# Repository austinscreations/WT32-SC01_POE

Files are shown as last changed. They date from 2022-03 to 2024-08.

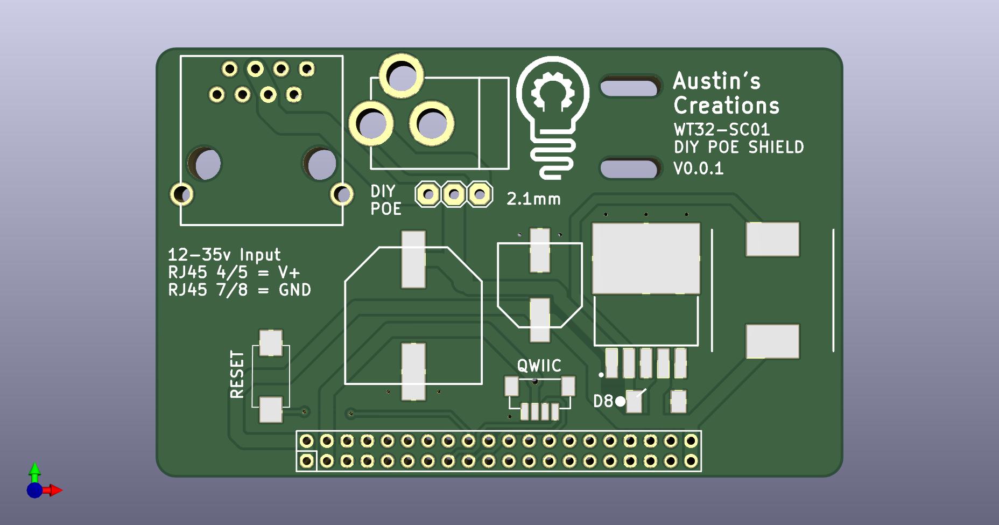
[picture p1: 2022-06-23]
WiFi POE shield/PCB/pictures/WT32SC01 wifi poe top.jpg

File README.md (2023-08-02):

# WT32-SC01_POE

2023-06-28:

New sheild has been designed that is more universal. the deisgn is much smaller. uses a single 1.25mm jst conenctor to connect to the wt32-sc01 PLUS display.
adapter has been built for the WT32-S3-86s (replaces the 86v) 4" display. adapter in the works to support the orginal display as well

2022-06-23: renamed the repo as this project has evolved

There are now two shields designed for the wt32-sc01 display.
- one offers Ethernet + 802.1af POE
- second offers passive 12-24v POE + a 2.1mm jack

the thought with a passive board is that it's smaller allowing for more compact case designs to be built. and if you prefer to use 802.1af POE with the 2.1mm jack you can very eaily use a standard POE injector that normally cost about $6 from aliexpress to gain such functionality. with teh apssive baord however you are limited to using wifi.

both shields also equipped with qwiic connector for easy i2c support

designed for the use case of using the panel for homeautomation, code and gui in progress.

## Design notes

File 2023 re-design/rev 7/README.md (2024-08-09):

latest version of the WT32 Ethernet POE
works directly on the WT32-SC01 Plus, and adapters will be availble for the orginal Wt32 screen and the square 86s/86v screen

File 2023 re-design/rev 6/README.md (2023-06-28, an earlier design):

# things to note

With the 86v panel you'd need both the POE module but also the adapter. along with doing modifications to the panel PCB to accept ethernet.
video of doing this modification here: <https://www.youtube.com/watch?v=REbtDBVKIto>

even with doing JLCPCBs PCBA you will need to add the ethernet jack - from mouser ARJM11D7-114-AB-EW2
I've been sourcing the POE from aliexpress - it has 2 pins on one end, 4 on the other. 12v output SDAPO DP1435
Then you need an 8 pin 1.25mm dual head JST connector. pinout should be the same pin 1 to pin 1 etc. i've been buying these from aliexpress in 100mmm length

Becuase part numbers and links change somewhat often i won't post any here but feel free to reach out on discord if you need help.

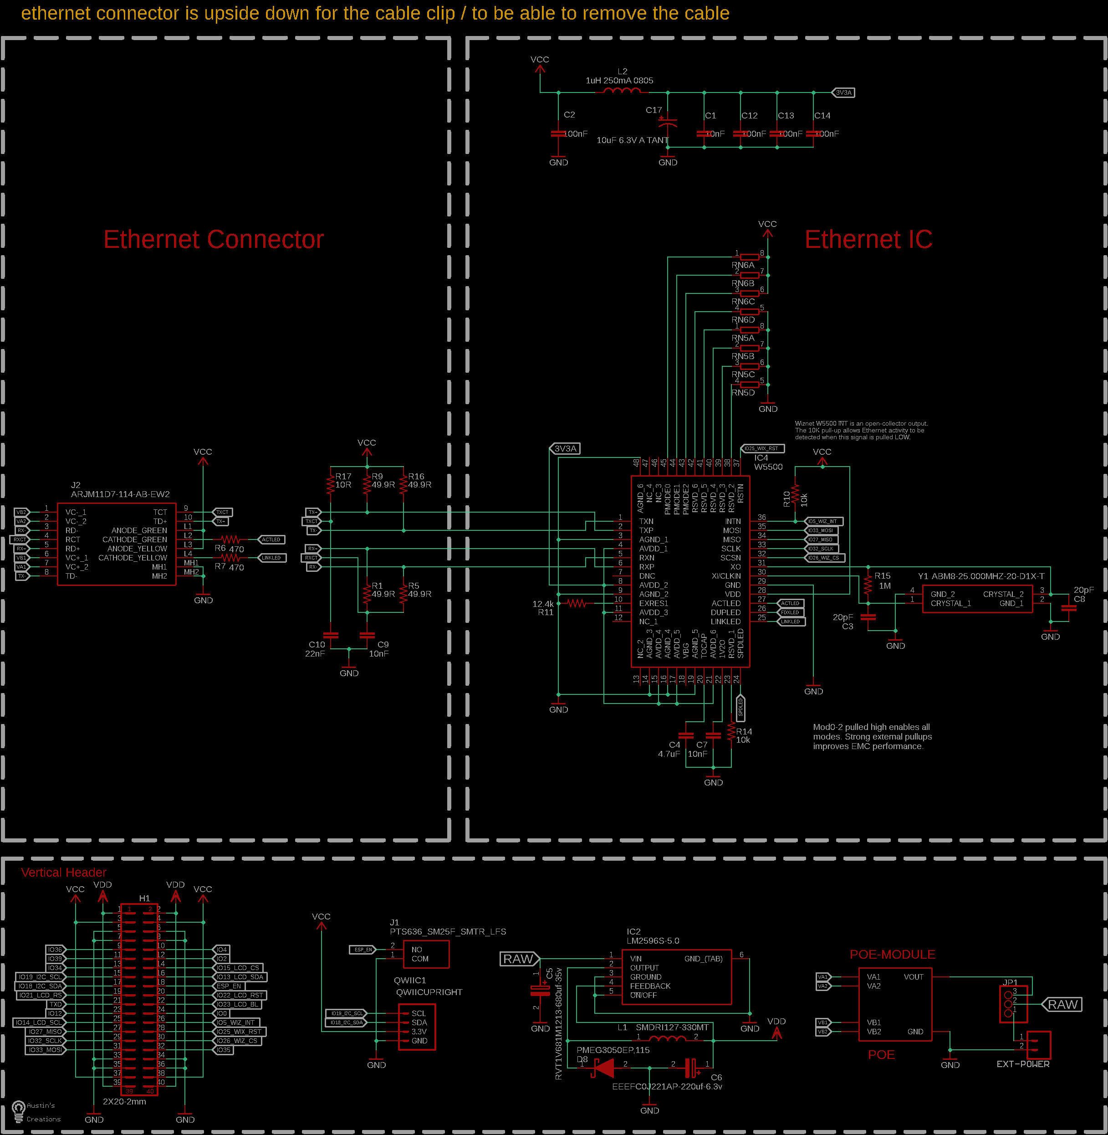
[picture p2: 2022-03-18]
Ethernet POE shield/PCB/pictures/schematic.png

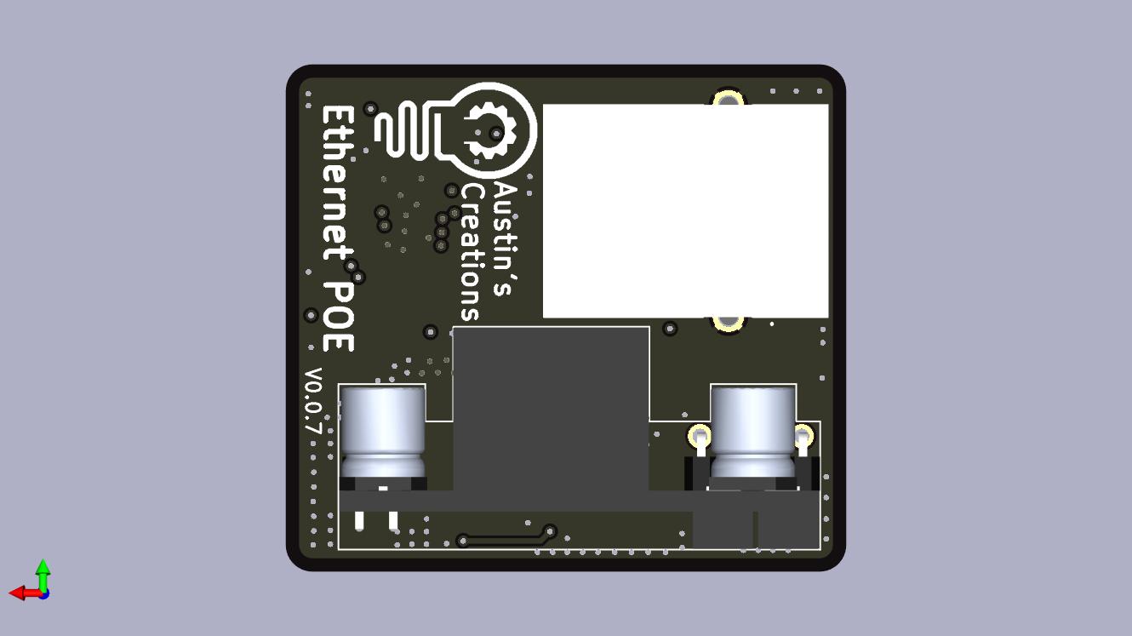
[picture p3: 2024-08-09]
2023 re-design/rev 7/WT32 ethernet POE 007 bottom.jpg

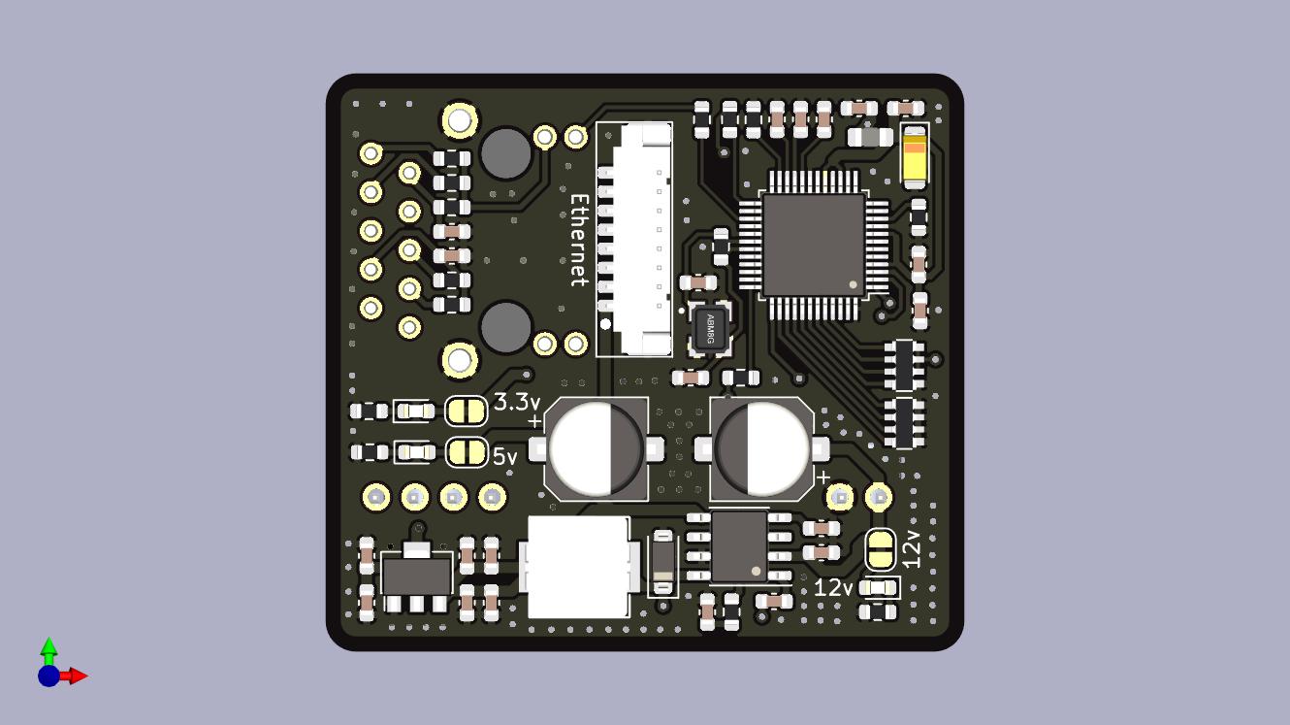
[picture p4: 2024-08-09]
2023 re-design/rev 7/WT32 ethernet POE 007 top.jpg

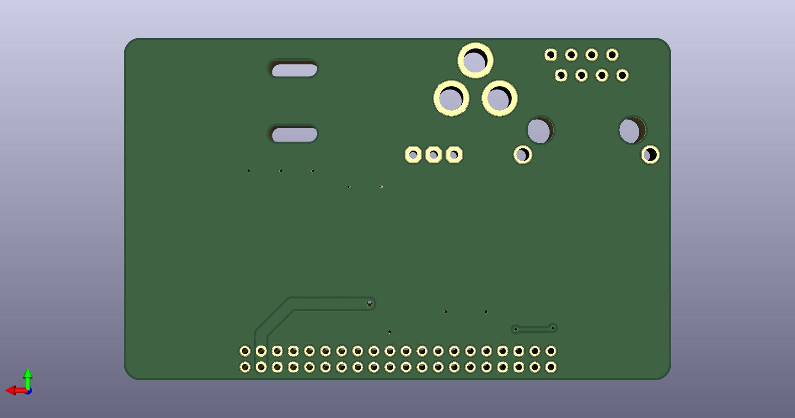
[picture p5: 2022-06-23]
WiFi POE shield/PCB/pictures/WT32SC01 wifi poe bottom.jpg

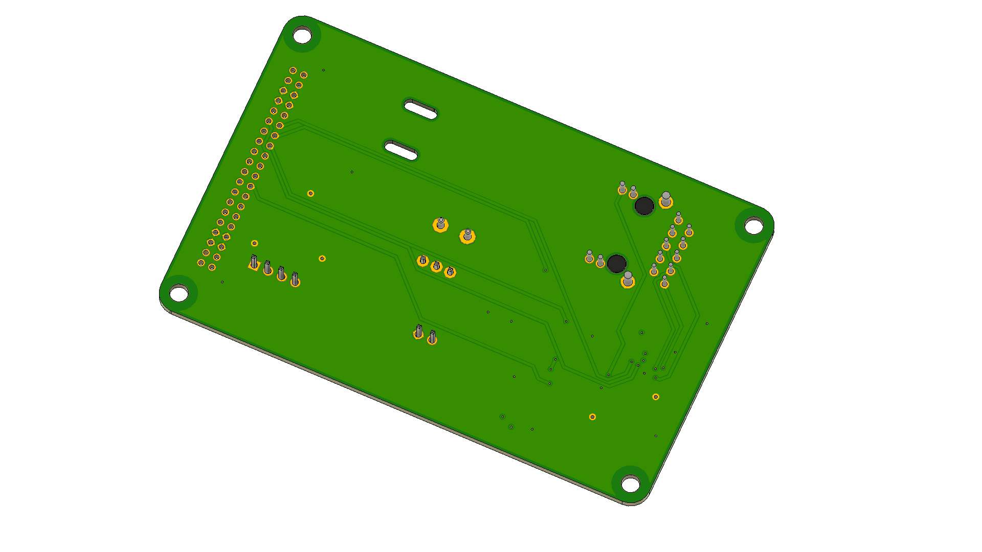
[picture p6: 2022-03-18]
Ethernet POE shield/PCB/pictures/WT32SC01-POE bottom.png

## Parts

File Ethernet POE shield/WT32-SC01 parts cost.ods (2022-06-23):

Part | Part Number | needed qty | cost | Purchase qty | per item | total | brd qty | current stock | total needed
680uf-35v | C98216 | 1 | 4.37 | 10 | 0.437 | 0.437 | 0 |  | 0
220uf-6.3v | C401613 | 1 | 4.39 | 30 | 0.1463333333 | 0.1463333333 | 0 |  | 0
0603 20pf | C105621 | 2 | 2.05 | 500 | 0.0041 | 0.0082 | 0 |  | 0
0603 4.7uF | C152930 | 1 | 3.92 | 200 | 0.0196 | 0.0196 | 0 |  | 0
0603 22nf | C302044 | 1 | 3.55 | 500 | 0.0071 | 0.0071 | 0 |  | 0
0603 10nf | C141077 | 2 | 4.6 | 500 | 0.0092 | 0.0184 | 0 |  | 0
0603 100nf | C83060 | 8 | 1.6 | 500 | 0.0032 | 0.0256 | 0 |  | 0
buttons | C410373 | 2 | 6.12 | 100 | 0.0612 | 0.1224 | 0 |  | 0
Ethernet connector |  | 1 | 6 | 1 | 6 | 6 | 0 |  | 0
25mhz crystal | C258949 | 1 | 6.09 | 50 | 0.1218 | 0.1218 | 0 |  | 0
POE module |  | 1 | 31.54 | 5 | 6.308 | 6.308 | 0 |  | 0
4pin jst sh | C145956 | 2 | 6.4 | 120 | 0.0533333333 | 0.1066666667 | 0 |  | 0
PMEG4050EP Diode | C96235 | 2 | 2.7 | 10 | 0.27 | 0.54 | 0 |  | 0
2pin terminal block | C192779 | 1 | 1.98 | 10 | 0.198 | 0.198 | 0 |  | 0
LM2596S-5.0 | C347421 | 1 | 7.09 | 10 | 0.709 | 0.709 | 0 |  | 0
w5500 Ethernet IC | C32843 | 1 | 7.94 | 1 | 7.94 | 7.94 | 0 |  | 0
330mt inductor | C9400 | 1 | 5.43 | 30 | 0.181 | 0.181 | 0 |  | 0
1x3 pin header | C213447 | 1 | 2.56 | 1500 | 0.0017066667 | 0.0017066667 | 0 |  | 0
0603 resistor 10ohm | C103222 | 1 | 1.7 | 1000 | 0.0017 | 0.0017 | 0 |  | 0
0603 resistor 49.9ohm | C103679 | 4 | 1.7 | 1000 | 0.0017 | 0.0068 | 0 |  | 0
0603 resistor 470 ohm | C25241 | 3 | 1.1 | 1000 | 0.0011 | 0.0033 | 0 |  | 0
0603 resistor 10k | C103199 | 2 | 1.7 | 1000 | 0.0017 | 0.0034 | 0 |  | 0
0603 resistor 12.4k | C269455 | 1 | 3 | 1000 | 0.003 | 0.003 | 0 |  | 0
0603 resistor 1M | C328343 | 1 | 2.9 | 1000 | 0.0029 | 0.0029 | 0 |  | 0
resistor network 10k | C29718 | 4 | 3.2 | 500 | 0.0064 | 0.0256 | 0 |  | 0
1uH 250mA 0805 | C98325 | 1 | 1.29 | 20 | 0.0645 | 0.0645 | 0 |  | 0
10uF tant capacitor | C127946 | 1 | 3.71 | 50 | 0.0742 | 0.0742 | 0 |  | 0
2x20 pin header 2mm | C376094 | 1 | 3.04 | 10 | 0.304 | 0.304 | 0
PCB's |  | 1 | 90 | 10 | 9 | 9 | 0
 | total creates % | % creates total
Total | 80 | 68.09
Markup | 52.73% | 30.00%
board cost | 52.38
purchase cost | 0.00
Shop 1 (pcb's) | 9.00
Shop 2 (aliexpress)
Shop 3 (lcsc) | 43.38
Automated assembly
Part | Part Number | needed qty | cost | Purchase qty | per item | total | brd qty | current stock | total needed
JLCPCB 10pcs |  | 1 | 260 | 10 | 26 | 26 | 0
POE module |  | 1 | 31.54 | 5 | 6.308 | 6.308
Ethernet connector |  | 1 | 6 | 1 | 6 | 6
4pin jst sh | C145956 | 2 | 6.4 | 120 | 0.0533333333 | 0.1066666667
1x3 pin header | C213447 | 1 | 2.56 | 1500 | 0.0017066667 | 0.0017066667
2x20 pin header 2mm | C376094 | 1 | 3.04 | 10 | 0.304 | 0.304
JLCPCB 50pcs |  | 1 | 660 | 50 | 13.2 | 13.2
Total | 60 | 50
Markup | 23.15% | 39.20%
 |  |  | 11.2796266667 | 14.08
board cost | 48.72
board cost | 35.92
Shop 1 (pcb's) | 26.00 | 13.2
Shop 2 ()
Shop 3 (parts) | 22.72 | 22.72

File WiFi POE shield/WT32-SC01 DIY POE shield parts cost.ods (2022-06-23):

Part | Part Number | needed qty | cost | Purchase qty | per item | total | brd qty | current stock | total needed
680uf-35v | C98216 | 1 | 4.37 | 10 | 0.437 | 0.437 | 0 |  | 0
220uf-6.3v | C401613 | 1 | 4.39 | 30 | 0.1463333333 | 0.1463333333 | 0 |  | 0 | C2895278
LM2596S-5.0 | C347421 | 1 | 7.09 | 10 | 0.709 | 0.709 | 0 |  | 0
330mt inductor | C9400 | 1 | 5.43 | 30 | 0.181 | 0.181 | 0 |  | 0
PMEG4050EP Diode | C96235 | 1 | 2.7 | 10 | 0.27 | 0.27 | 0 |  | 0
2.1mm power jack | C319099 | 1 | 3.95 | 50 | 0.079 | 0.079 | 0 |  | 0
1x3 pin header | C213447 | 1 | 2.56 | 1500 | 0.0017066667 | 0.0017066667 | 0 |  | 0
buttons | C410373 | 1 | 6.12 | 100 | 0.0612 | 0.0612 | 0 |  | 0
Ethernet connector | C386763 | 1 | 5.69 | 10 | 0.569 | 0.569 | 0 |  | 0
4pin jst sh vertical | C145961 | 1 | 8.29 | 120 | 0.0690833333 | 0.0690833333 | 0 |  | 0
2x20 pin header 2mm | C376094 | 1 | 3.04 | 10 | 0.304 | 0.304 | 0 |  | 0
PCB's |  | 1 | 75 | 10 | 7.5 | 7.5 | 0 |  | 0
Total | 30
Markup | -1.08%
board cost | 30.33
purchase cost | 0.00
Shop 1 (pcb's) | 7.50
Shop 2 (aliexpress)
Shop 3 (lcsc) | 22.83
SMD assembly:
PCB's |  | 1 | 200 | 20 | 10 | 10 | 0 |  | 0
2.1mm power jack | C319099 | 1 | 3.95 | 50 | 0.079 | 0.079 | 0 |  | 0
2x20 pin header 2mm | C376094 | 1 | 3.04 | 10 | 0.304 | 0.304 | 0 |  | 0
1x3 pin header | C213447 | 1 | 2.56 | 1500 | 0.0017066667 | 0.0017066667 | 0 |  | 0
Total | 30
Markup | 188.89%
board cost | 10.38
purchase cost | 0.00
Shop 1 (pcb's) | 10.00
Shop 2 (aliexpress)
Shop 3 (lcsc) | 0.38

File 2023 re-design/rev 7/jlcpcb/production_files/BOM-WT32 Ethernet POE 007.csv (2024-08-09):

Comment | Designator | Footprint | LCSC
LM1117-3.3 | U3 | SOT-89-3 | C126019
10uF 6.3V A TANT | C7 | CP_EIA-3216-18_Kemet-A | C127946
100nF | C12,C13,C14,C16,C4 | C_0603_1608Metric | C14663
1uF | C22,C24 | C_0603_1608Metric | C15849
2.2nF | C6 | C_0603_1608Metric | C1604
20pF | C1,C2 | C_0603_1608Metric | C1648
4.7uF | C11 | C_0603_1608Metric | C19666
22nF | C17 | C_0603_1608Metric | C21122
Ethernet | J1 | 8 pin jst 1.25 vertical | C225110
10R | R12 | R_0603_1608Metric | C22859
1M | R1 | R_0603_1608Metric | C22935
470R | R10,R11 | R_0603_1608Metric | C23179
49.9R | R6,R7,R8,R9 | R_0603_1608Metric | C23185
10k | R13,R14,R15,R2,R3 | R_0603_1608Metric | C25804
47k | R4 | R_0603_1608Metric | C25819
25MHz_SMD_Crystal_Resonator | Y1 | 25MHz_SMD_Crystal_Resonator | C258949
10k | RN1,RN2 | R_Array_Convex_4x0603 | C29718
82uH 2A | L2 | IND-SMD_L7.1-W6.6 | C2983095
12.4k | R5 | R_0603_1608Metric | C310267
W5500 | U1 | LQFP-48_7x7mm_P0.5mm | C32843
TPS5405DR | U2 | SOIC-8_3.9x4.9mm_P1.27mm | C488409
150uF 25v | C18,C3 | CP_Elec_6.3x7.7 | C494825
10nF | C10,C15,C8,C9 | C_0603_1608Metric | C57112
red | D2,D3,D4 | LED_0603_1608Metric | C72038
DSK24 | D1 | D_SOD-123 | C908229
10uF 25v | C19,C20,C21,C23,C5 | C_0603_1608Metric | C96446
1uH 250mA 0805 | L1 | L_0805_2012Metric | C98325

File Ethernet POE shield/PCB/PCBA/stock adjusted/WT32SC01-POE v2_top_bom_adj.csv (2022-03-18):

Comment | Designator | Footprint | LCSC Part #
1M | R15 | R0603 | C328343
1uH 250mA 0805 | L2 | L2012C | C98325
4.7uF | C4 | C0603 | C152930
10R | R17 | R0603 | C103222
10k | R10 R14 | R0603 | C103199
10nF | C1 C7 C9 | C0603 | C57112
10uF 6.3V A TANT | C17 | A/3216-18W | C127946
12.4k | R11 | R0603 | C269455
20pF | C3 C8 | C0603 | C105621
22nF | C10 | C0603 | C302044
49.9R | R1 R5 R9 R16 | R0603 | C103679
100nF | C2 C12 C13 C14 | C0603 | C83060
470R | R6 R7 | R0603 | C25241
ABM8-25.000MHZ-20-D1X-T | Y1 | ABM825000MHZ10B1UT | C258949
EEEFC0J221AP-220uf-6.3v | C6 | CAPAE830X650N | C401614
LM2596S-5.0 | IC2 | TO170P1435X465-6N | C347421
PMEG4050EP 115 | D8 | PMEG4050EP115 | C96234
PTS636_SM25F_SMTR_LFS | J1 | PTS636SM25FSMTRLFS | C410373
QWIICUPRIGHT | QWIIC1 | BM04B-SRSS-TB | C145961
RVT1V681M1213-680uf-35v | C5 | CAPAE1350X1400N | C249685
SMDRI127-330MT | L1 | INDPM120120X800N | C9400
W5500 | IC4 | QFP50P900X900X160-48N | C32843
10k | RN5 RN6 | R1206 | C29718

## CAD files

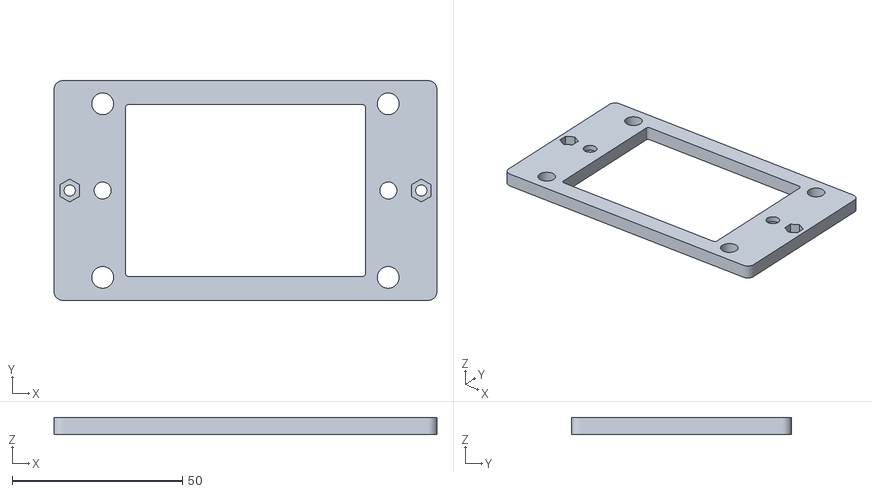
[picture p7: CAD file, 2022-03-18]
case designs/ethernet/AUS mount.stl
112.6 x 64.6 x 5.00

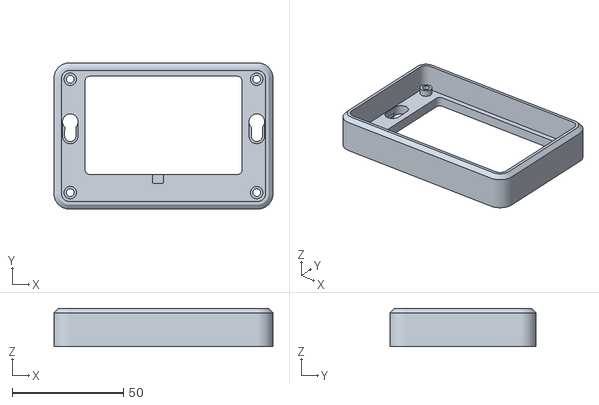
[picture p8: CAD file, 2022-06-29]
case designs/wifi/no usb access/WT32-SC01 wifi case AUS 3mm standoff no usb.stl
98.6 x 65.8 x 17.2

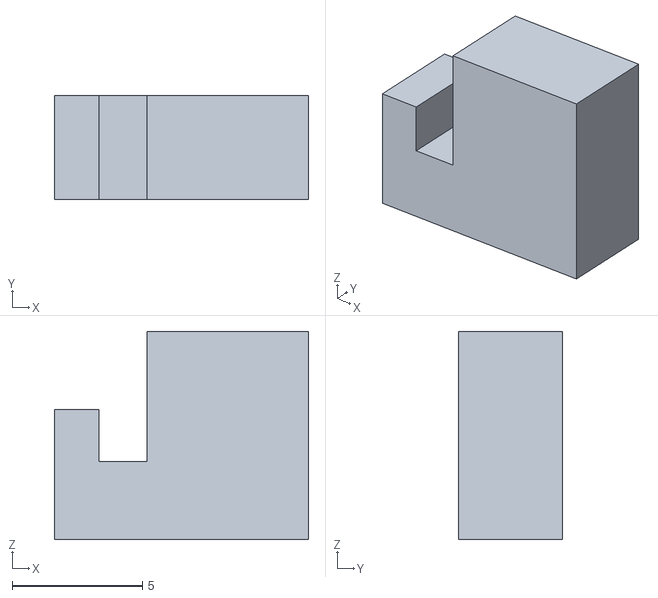
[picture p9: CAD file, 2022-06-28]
case designs/wifi/wifi pcb clip.stl
9.75 x 4.00 x 8.00

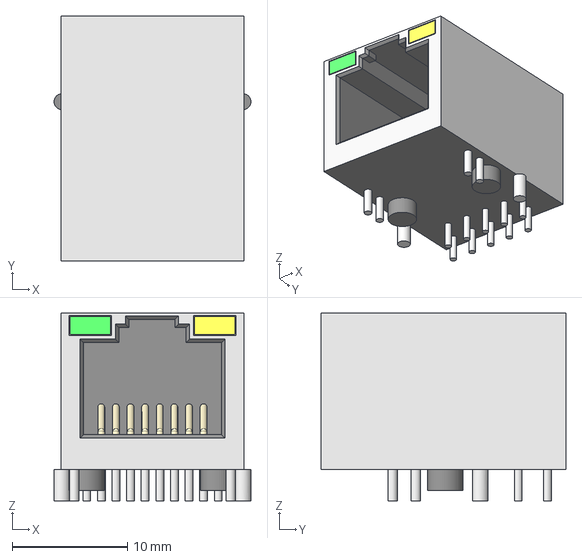
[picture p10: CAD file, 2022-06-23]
Ethernet POE shield/PCB/CAD/ARJM11D7114ABEW2.step
17.1 x 21.3 x 16.3 mm

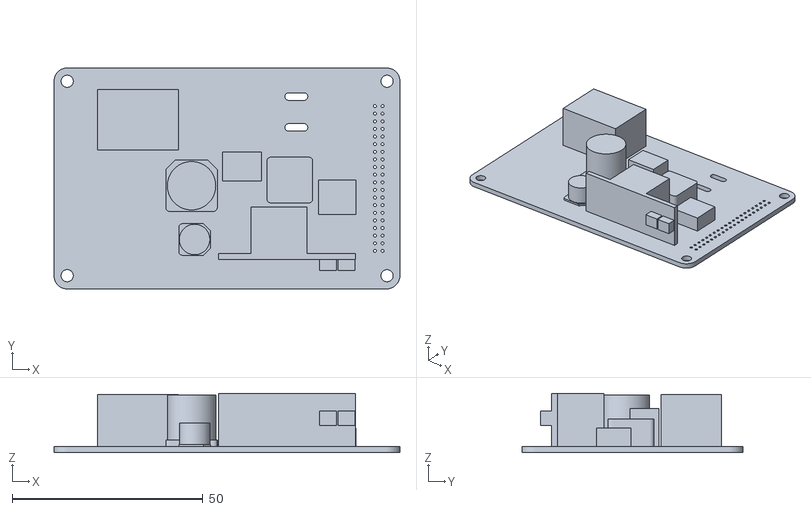
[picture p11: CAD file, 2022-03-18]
case designs/ethernet/sheild test v0.0.1.stl
90.8 x 58.0 x 15.6

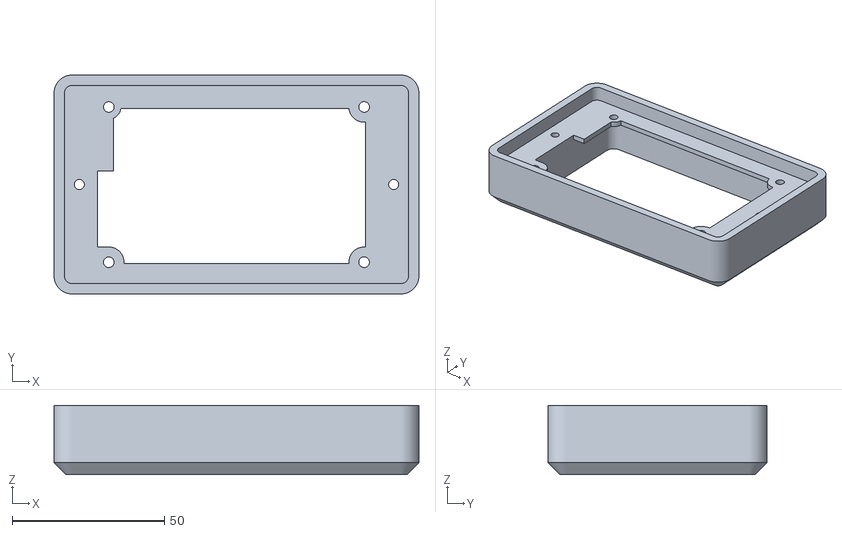
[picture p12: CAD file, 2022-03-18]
case designs/ethernet/screen case extra height.stl
120.0 x 72.0 x 22.8

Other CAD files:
case designs/wifi/no usb access/WT32-SC01 wifi case NA 3mm standoff no usb.stl
case designs/wifi/WT32-SC01 wifi case AUS 3mm standoff.stl
case designs/wifi/no usb access/WT32-SC01 wifi case AUS 6mm standoff no usb.stl
case designs/wifi/WT32-SC01 wifi case NA 3mm standoff.stl
case designs/ethernet/NA mount.stl
case designs/wifi/no usb access/WT32-SC01 wifi case NA 6mm standoff no usb.stl
case designs/wifi/WT32-SC01 wifi case AUS 6mm standoff.stl
case designs/wifi/WT32-SC01 wifi case NA 6mm standoff.stl
case designs/WT32-SC01 wifi case.skp

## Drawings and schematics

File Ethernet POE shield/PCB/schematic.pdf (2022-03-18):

Ethernet Connector | Ethernet IC

# ethernet connector is upside down for the cable clip / to be able to remove the cable

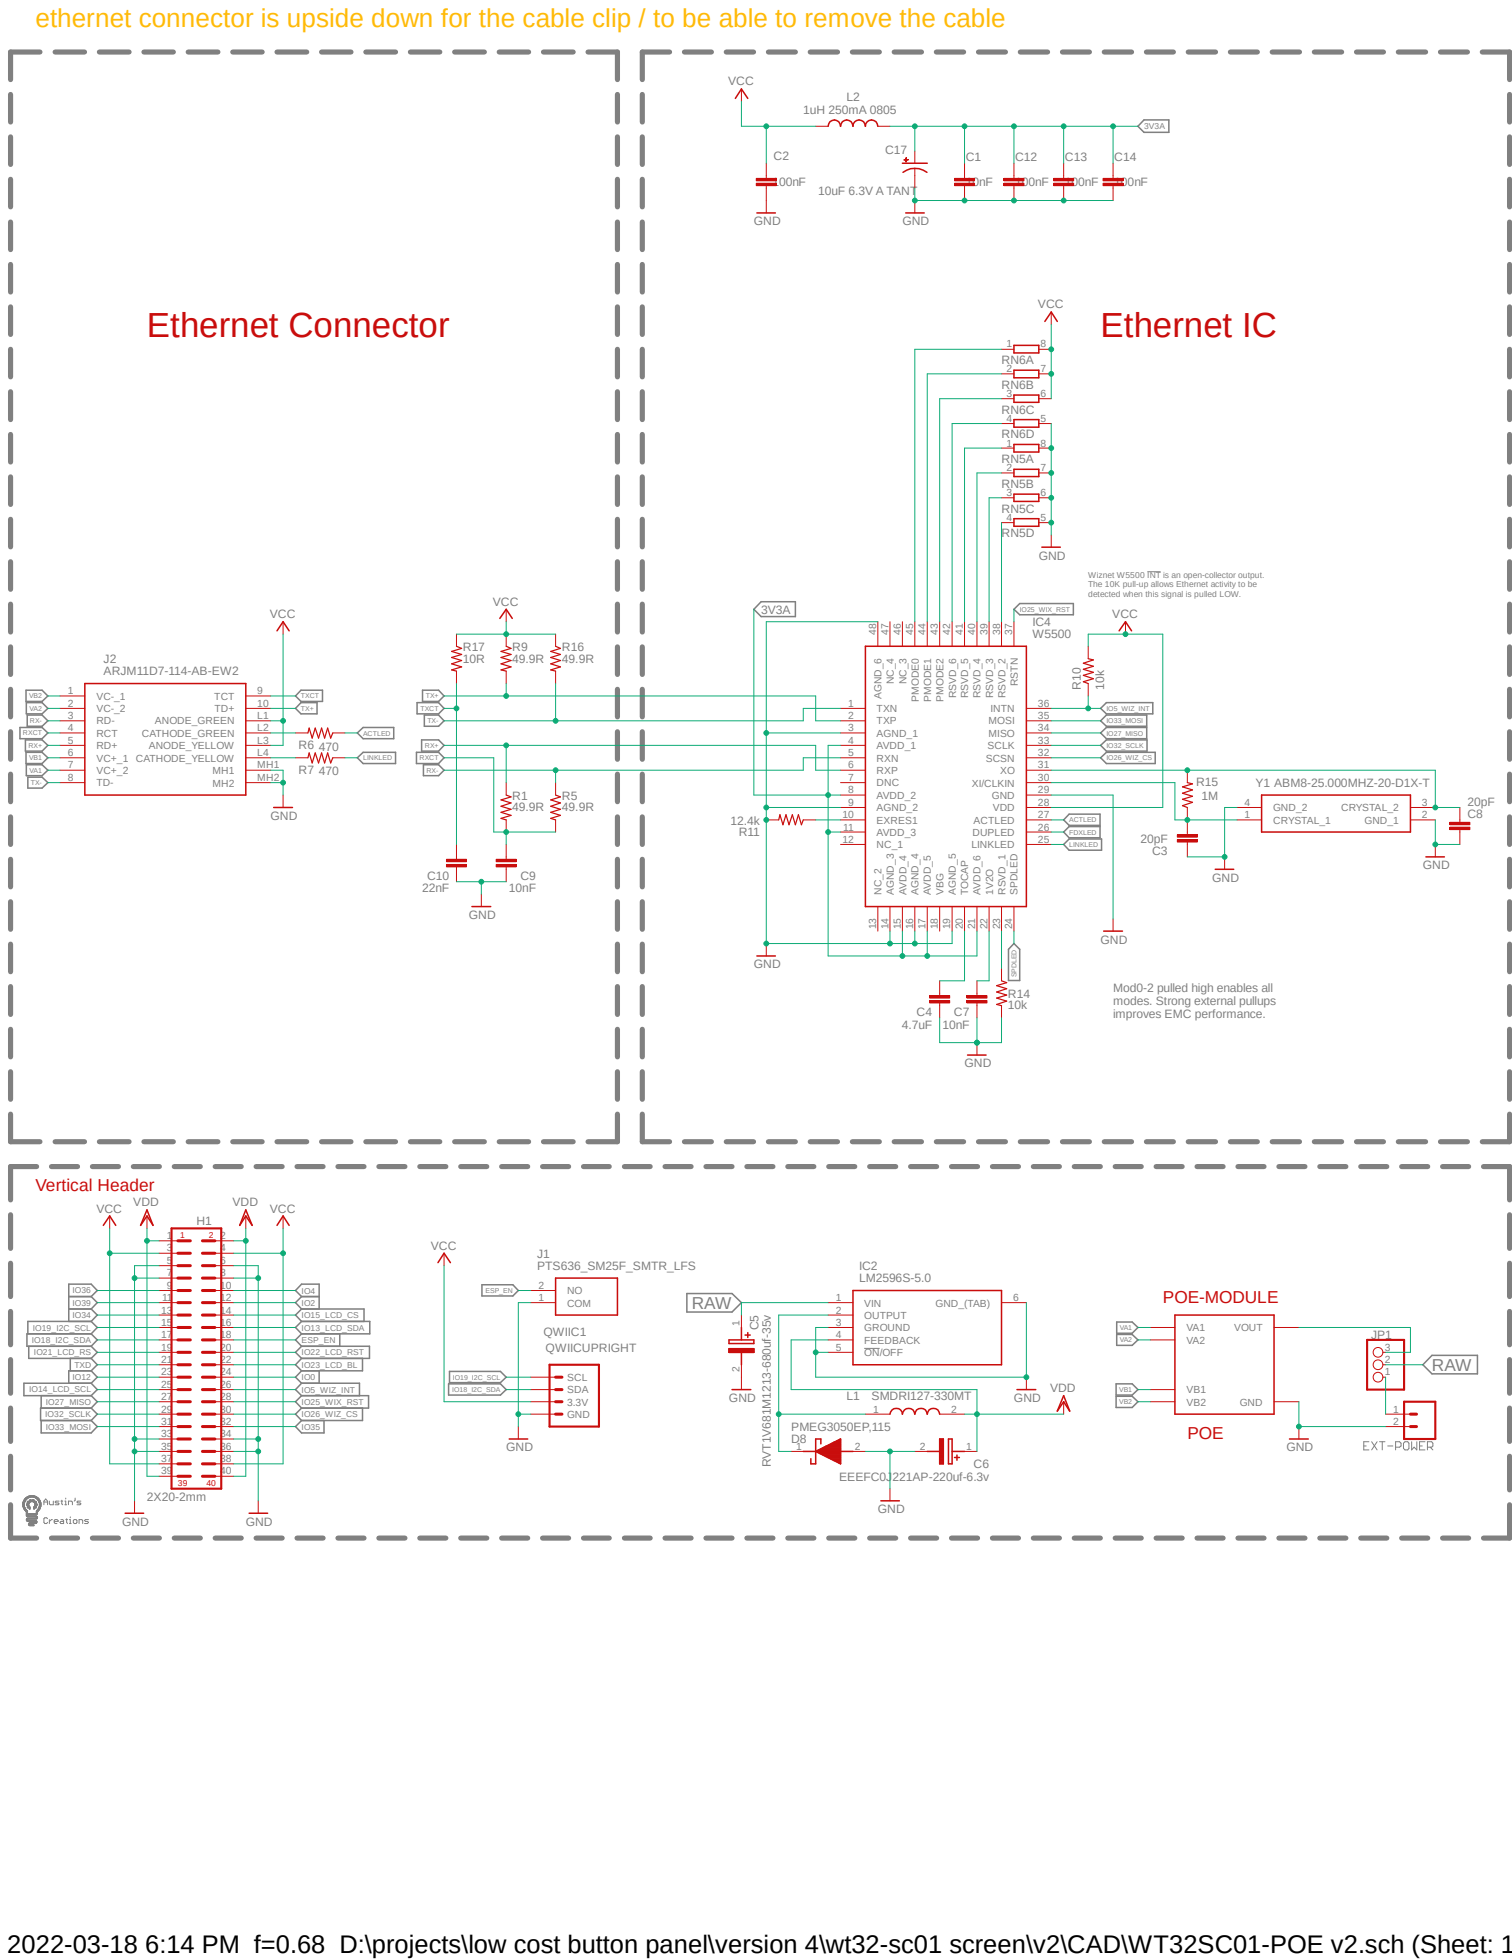
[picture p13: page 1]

Wiznet W5500 INT is an open-collector output. The 10K pull-up allows Ethernet activity to be

detected when this signal is pulled LOW.

Mod0-2 pulled high enables all
modes. Strong external pullups
improves EMC performance.

2022-03-18 6:14 PM f=0.68 D:\projects\low cost button panel\version 4\wt32-sc01 screen\v2\CAD\WT32SC01-POE v2.sch (Sheet: 1/1)

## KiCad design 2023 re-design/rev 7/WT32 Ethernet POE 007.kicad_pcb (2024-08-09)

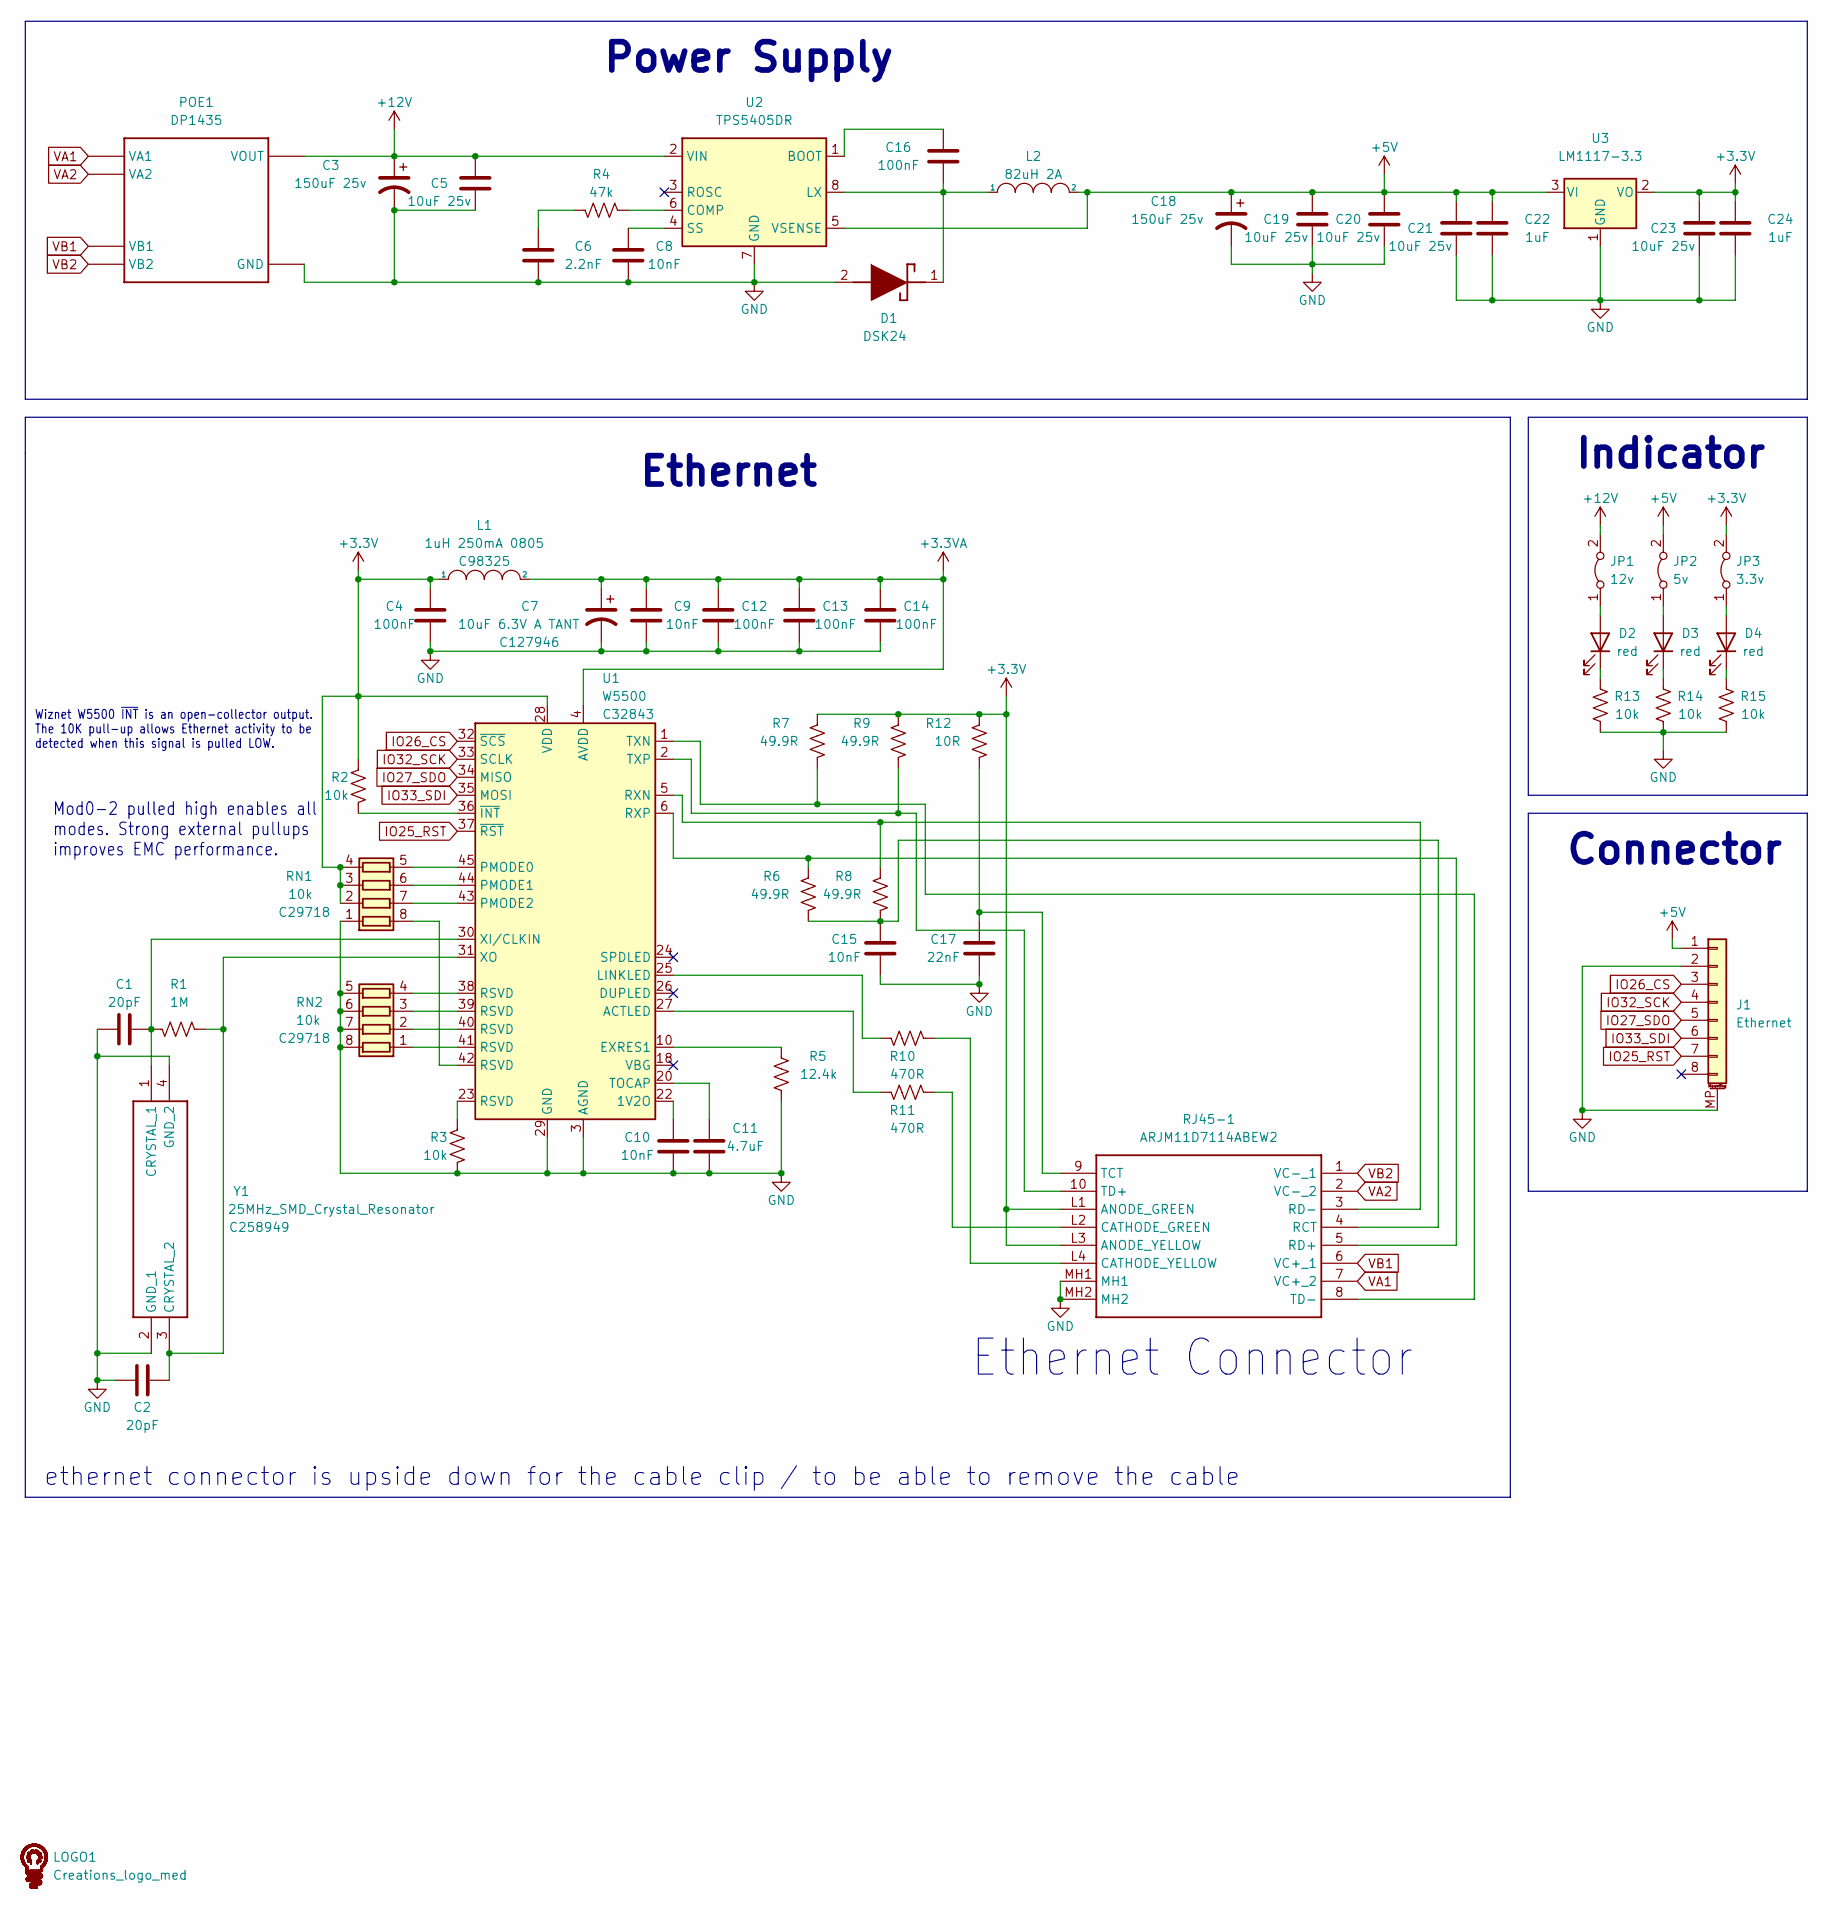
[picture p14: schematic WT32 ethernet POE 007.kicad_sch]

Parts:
C1, C2: 20pF; C_0603_1608Metric; LCSC C1648
C3, C18: 150uF 25v; CP_Elec_6.3x7.7; LCSC C494825
C4, C12, C13, C14, C16: 100nF; C_0603_1608Metric; LCSC C14663
C5, C19, C20, C21, C23: 10uF 25v; C_0603_1608Metric; LCSC C96446
C6: 2.2nF; C_0603_1608Metric; LCSC C1604
C7: 10uF 6.3V A TANT; CP_EIA-3216-18_Kemet-A; LCSC C127946
C8, C9, C10, C15: 10nF; C_0603_1608Metric; LCSC C57112
C11: 4.7uF; C_0603_1608Metric; LCSC C19666
C17: 22nF; C_0603_1608Metric; LCSC C21122
C22, C24: 1uF; C_0603_1608Metric; LCSC C15849
D1: DSK24; D_SOD-123; LCSC C908229
D2, D3, D4: red; LED_0603_1608Metric; LCSC C72038
J1: Ethernet; 8 pin jst 1.25 vertical; LCSC C225110
JP1: 12v; SolderJumper-2_P1.3mm_Bridged_RoundedPad1.0x1.5mm
JP2: 5v; SolderJumper-2_P1.3mm_Bridged_RoundedPad1.0x1.5mm
JP3: 3.3v; SolderJumper-2_P1.3mm_Bridged_RoundedPad1.0x1.5mm
L1: 1uH 250mA 0805; L_0805_2012Metric; LCSC C98325
L2: 82uH 2A; IND-SMD_L7.1-W6.6; LCSC C2983095
LOGO1: Creations_logo_med; Creations logo med
POE1: DP1435
R1: 1M; R_0603_1608Metric; LCSC C22935
R2, R3, R13, R14, R15: 10k; R_0603_1608Metric; LCSC C25804
R4: 47k; R_0603_1608Metric; LCSC C25819
R5: 12.4k; R_0603_1608Metric; LCSC C310267
R6, R7, R8, R9: 49.9R; R_0603_1608Metric; LCSC C23185
R10, R11: 470R; R_0603_1608Metric; LCSC C23179
R12: 10R; R_0603_1608Metric; LCSC C22859
RJ45-1: ARJM11D7114ABEW2
RN1, RN2: 10k; R_Array_Convex_4x0603; LCSC C29718
U1: W5500; LQFP-48_7x7mm_P0.5mm; LCSC C32843
U2: TPS5405DR; SOIC-8_3.9x4.9mm_P1.27mm; LCSC C488409
U3: LM1117-3.3; SOT-89-3; LCSC C126019
Y1: 25MHz_SMD_Crystal_Resonator; LCSC C258949

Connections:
+3.3V: C4.2, C23.2, C24.1, JP3.2 (B), L1.1, R2.2, R7.2, R9.2, R12.2, RJ45-1.L1 (ANODE_GREEN), RJ45-1.L3 (ANODE_YELLOW), RN1.2 (R2.1), RN1.3 (R3.1), RN1.4 (R4.1), U1.28 (VDD), U3.2 (VO)
+3.3VA: C7.1, C9.2, C12.2, C13.2, C14.2, L1.2, U1.4 (AVDD), U1.8 (AVDD), U1.11 (AVDD), U1.15 (AVDD), U1.17 (AVDD), U1.21 (AVDD)
+5V: C18.1, C19.2, C20.2, C21.2, C22.1, J1.1, JP2.2 (B), L2.2, U2.5 (VSENSE), U3.3 (VI)
+12V: C3.1, C5.2, JP1.2 (B), POE1.VOUT, U2.2 (VIN)
GND: C1.1, C2.1, C3.2, C4.1, C5.1, C6.1, C7.2, C8.1, C9.1, C10.1, C11.1, C12.1, C13.1, C14.1, C15.1, C17.1, C18.2, C19.1, C20.1, C21.1, C22.2, C23.1, C24.2, D1.2 (A), J1.2, J1.MP (MountPin), POE1.GND, R3.1, R5.1, R13.2, R14.1, R15.1, RJ45-1.MH1, RJ45-1.MH2, RN1.1 (R1.1), RN2.5 (R4.2), RN2.6 (R3.2), RN2.7 (R2.2), RN2.8 (R1.2), U1.3 (AGND), U1.9 (AGND), U1.14 (AGND), U1.16 (AGND), U1.19 (AGND), U1.29 (GND), U1.48 (AGND), U2.7 (GND), U3.1 (GND), Y1.2 (GND_1), Y1.4 (GND_2)
IO25_RST: J1.7, U1.37 (~RST)
IO26_CS: J1.3, U1.32 (~SCS)
IO27_SDO: J1.5, U1.34 (MISO)
IO32_SCK: J1.4, U1.33 (SCLK)
IO33_SDI: J1.6, U1.35 (MOSI)
unnamed: C6.2, R4.2
unnamed: C16.2, D1.1 (K), L2.1, U2.8 (LX)
unnamed: D2.2 (A), JP1.1 (A)
unnamed: D2.1 (K), R13.1
unnamed: D3.2 (A), JP2.1 (A)
unnamed: D3.1 (K), R14.2
unnamed: D4.2 (A), JP3.1 (A)
unnamed: D4.1 (K), R15.2
unnamed: R3.2, U1.23 (RSVD)
unnamed: R11.1, RJ45-1.L2 (CATHODE_GREEN)
unnamed: R10.1, RJ45-1.L4 (CATHODE_YELLOW)
unnamed: C15.2, R6.1, R8.1, RJ45-1.4 (RCT)
unnamed: R6.2, RJ45-1.5 (RD+), U1.6 (RXP)
unnamed: R8.2, RJ45-1.3 (RD-), U1.5 (RXN)
unnamed: C17.2, R12.1, RJ45-1.9 (TCT)
unnamed: R9.1, RJ45-1.10 (TD+), U1.2 (TXP)
unnamed: R7.1, RJ45-1.8 (TD-), U1.1 (TXN)
unnamed: RN1.8 (R1.2), U1.42 (RSVD)
unnamed: RN1.7 (R2.2), U1.43 (PMODE2)
unnamed: RN1.6 (R3.2), U1.44 (PMODE1)
unnamed: RN1.5 (R4.2), U1.45 (PMODE0)
unnamed: RN2.1 (R1.1), U1.41 (RSVD)
unnamed: RN2.2 (R2.1), U1.40 (RSVD)
unnamed: RN2.3 (R3.1), U1.39 (RSVD)
unnamed: RN2.4 (R4.1), U1.38 (RSVD)
unnamed: C10.2, U1.22 (1V2O)
unnamed: R11.2, U1.27 (ACTLED)
unnamed: R5.2, U1.10 (EXRES1)
unnamed: R10.2, U1.25 (LINKLED)
unnamed: C11.2, U1.20 (TOCAP)
unnamed: C1.2, R1.1, U1.30 (XI/CLKIN), Y1.1 (CRYSTAL_1)
unnamed: C2.2, R1.2, U1.31 (XO), Y1.3 (CRYSTAL_2)
unnamed: R2.1, U1.36 (~INT)
unnamed: C16.1, U2.1 (BOOT)
unnamed: R4.1, U2.6 (COMP)
unnamed: C8.2, U2.4 (SS)
VA1: POE1.VA1, RJ45-1.7 (VC+_2)
VA2: POE1.VA2, RJ45-1.2 (VC-_2)
VB1: POE1.VB1, RJ45-1.6 (VC+_1)
VB2: POE1.VB2, RJ45-1.1 (VC-_1)

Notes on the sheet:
Indicator
Power Supply
Connector
Ethernet
Ethernet Connector
ethernet connector is upside down for the cable clip / to be able to remove the cable
Wiznet W5500 ~{INT} is an open-collector output. The 10K pull-up allows Ethernet activity to be detected when this signal is pulled LOW.
Mod0-2 pulled high enables all modes. Strong external pullups improves EMC performance.

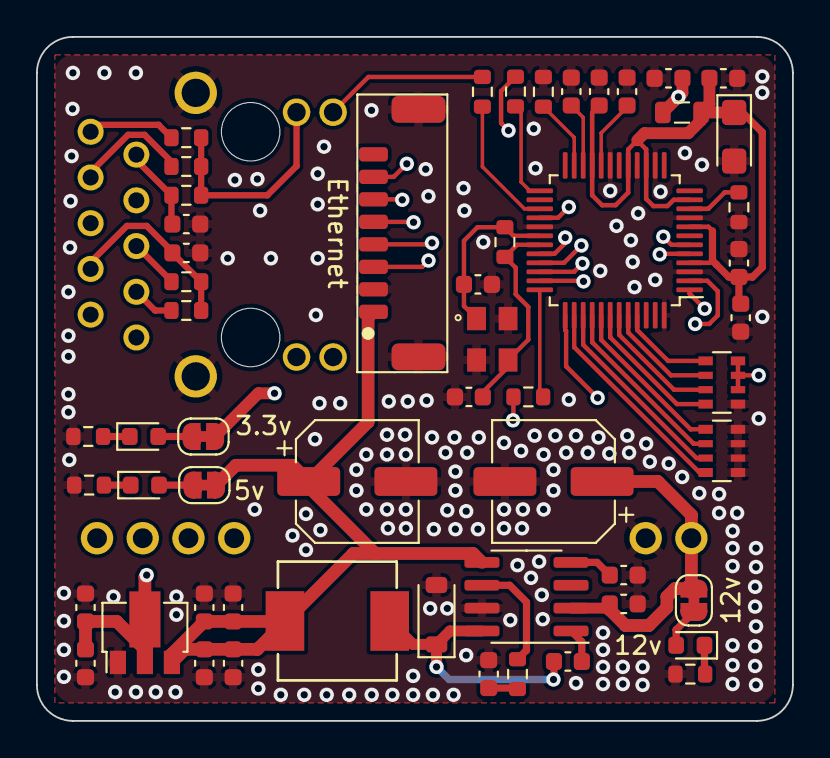
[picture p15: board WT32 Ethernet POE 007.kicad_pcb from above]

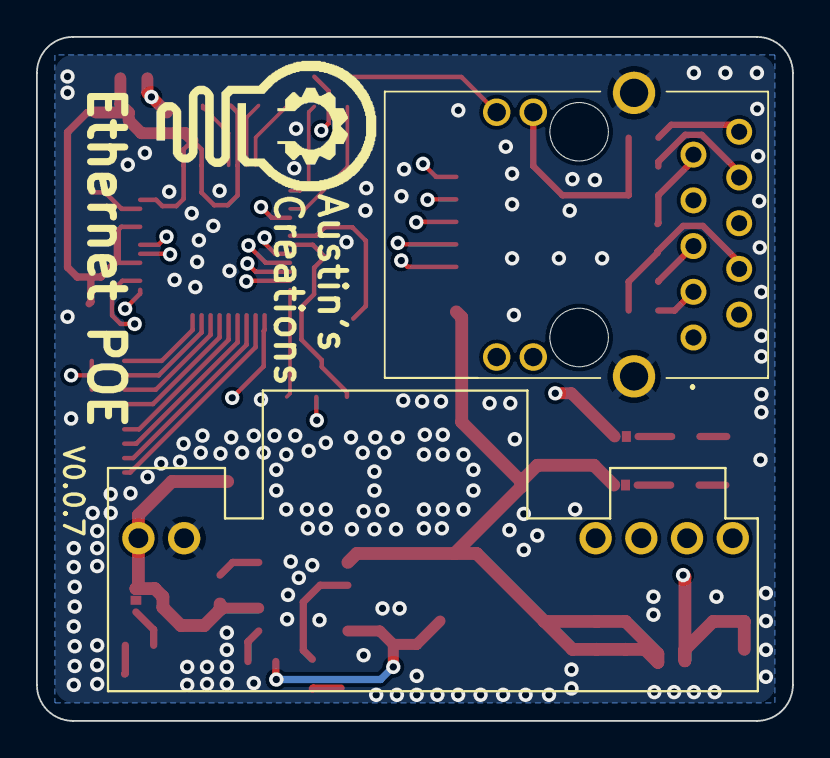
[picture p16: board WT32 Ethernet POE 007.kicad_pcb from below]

Board: 4 copper layers, 42.0 x 38.0 mm, 58 parts (3 on the bottom side), 50 nets.

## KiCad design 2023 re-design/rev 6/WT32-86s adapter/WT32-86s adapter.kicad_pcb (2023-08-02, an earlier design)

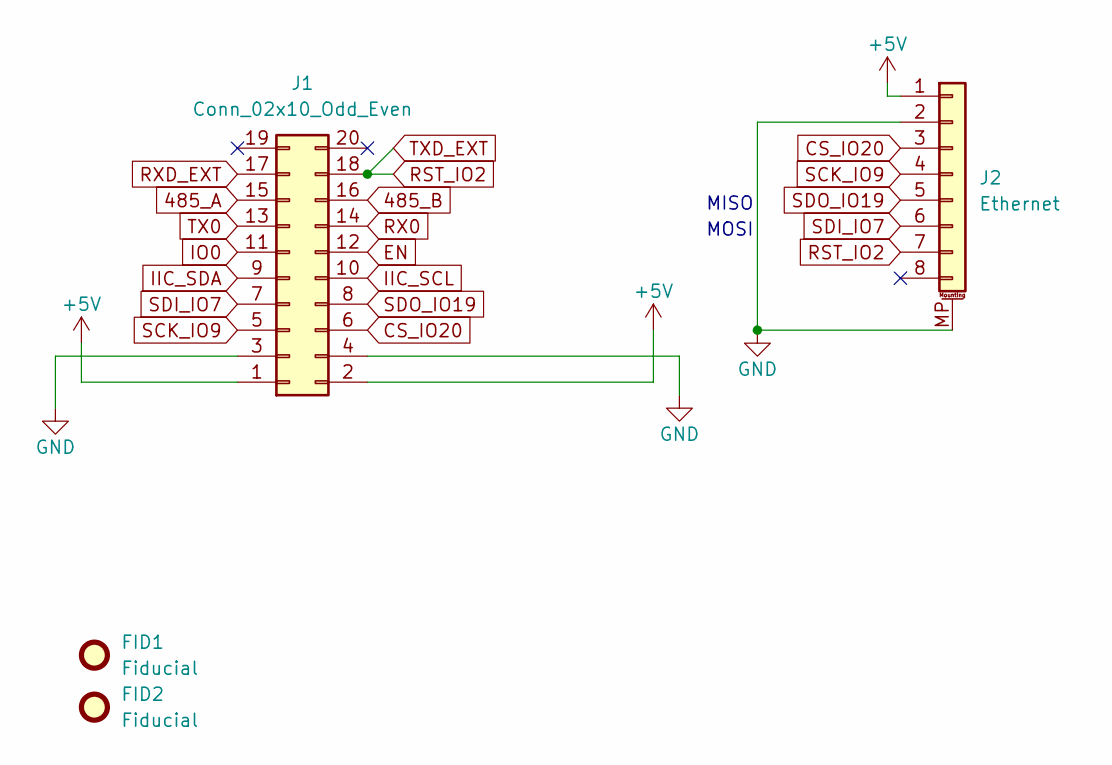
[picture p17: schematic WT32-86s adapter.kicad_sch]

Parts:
FID1, FID2: Fiducial; Fiducial_1mm_Mask2mm
J1: Conn_02x10_Odd_Even; PinHeader_2x10_P2.00mm_Vertical; LCSC C2935965
J2: Ethernet; JST_GH_SM08B-GHS-TB_1x08-1MP_P1.25mm_Horizontal; LCSC C225117

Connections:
485_A: J1.15
485_B: J1.16
+5V: J1.1, J1.2, J2.1
CS_IO20: J1.6, J2.3
EN: J1.12
GND: J1.3, J1.4, J2.2, J2.MP (MountPin)
IIC_SCL: J1.10
IIC_SDA: J1.9
IO0: J1.11
RX0: J1.14
RXD_EXT: J1.17
SCK_IO9: J1.5, J2.4
SDI_IO7: J1.7, J2.6
SDO_IO19: J1.8, J2.5
TX0: J1.13
TXD_EXT: J1.18, J2.7

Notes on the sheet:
MOSI
MISO

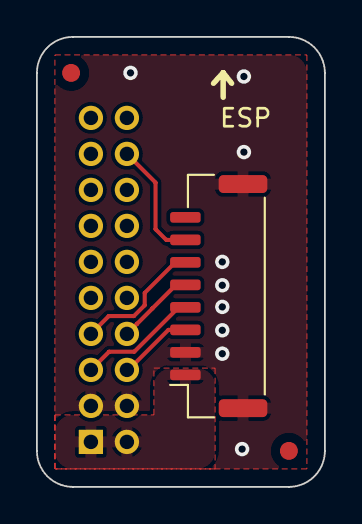
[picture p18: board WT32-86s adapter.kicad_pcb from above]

Board: 2 copper layers, 16.0 x 25.0 mm, 4 parts (1 on the bottom side), 7 nets.

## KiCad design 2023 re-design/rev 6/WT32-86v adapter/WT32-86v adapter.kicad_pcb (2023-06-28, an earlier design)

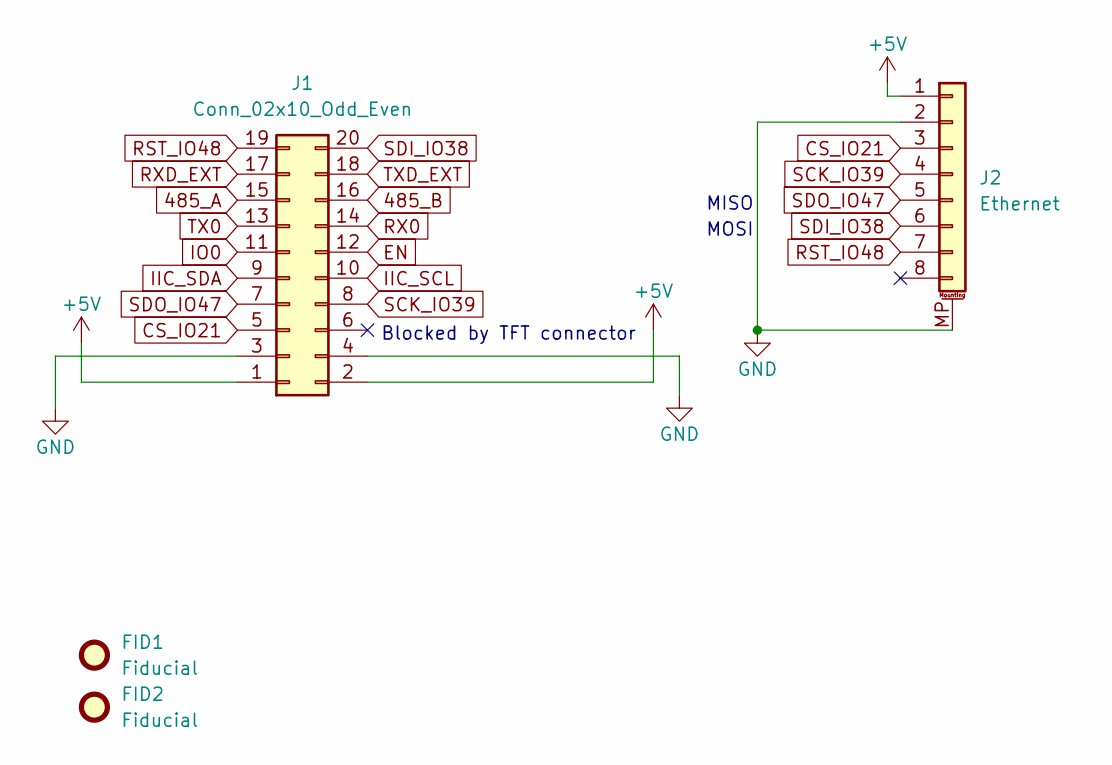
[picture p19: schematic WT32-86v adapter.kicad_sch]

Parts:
FID1, FID2: Fiducial; Fiducial_1mm_Mask2mm
J1: Conn_02x10_Odd_Even; PinHeader_2x10_P2.00mm_Vertical; LCSC C2935965
J2: Ethernet; JST_GH_SM08B-GHS-TB_1x08-1MP_P1.25mm_Horizontal; LCSC C225117

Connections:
485_A: J1.15
485_B: J1.16
+5V: J1.1, J1.2, J2.1
CS_IO21: J1.5, J2.3
EN: J1.12
GND: J1.3, J1.4, J2.2, J2.MP (MountPin)
IIC_SCL: J1.10
IIC_SDA: J1.9
IO0: J1.11
RST_IO48: J1.19, J2.7
RX0: J1.14
RXD_EXT: J1.17
SCK_IO39: J1.8, J2.4
SDI_IO38: J1.20, J2.6
SDO_IO47: J1.7, J2.5
TX0: J1.13
TXD_EXT: J1.18

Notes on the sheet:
Blocked by TFT connector
MOSI
MISO

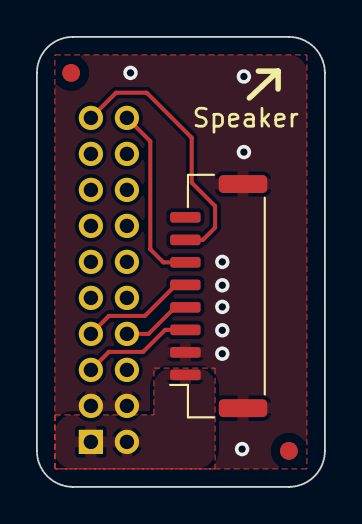
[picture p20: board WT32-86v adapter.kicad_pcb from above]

Board: 2 copper layers, 16.0 x 25.0 mm, 4 parts (1 on the bottom side), 7 nets.

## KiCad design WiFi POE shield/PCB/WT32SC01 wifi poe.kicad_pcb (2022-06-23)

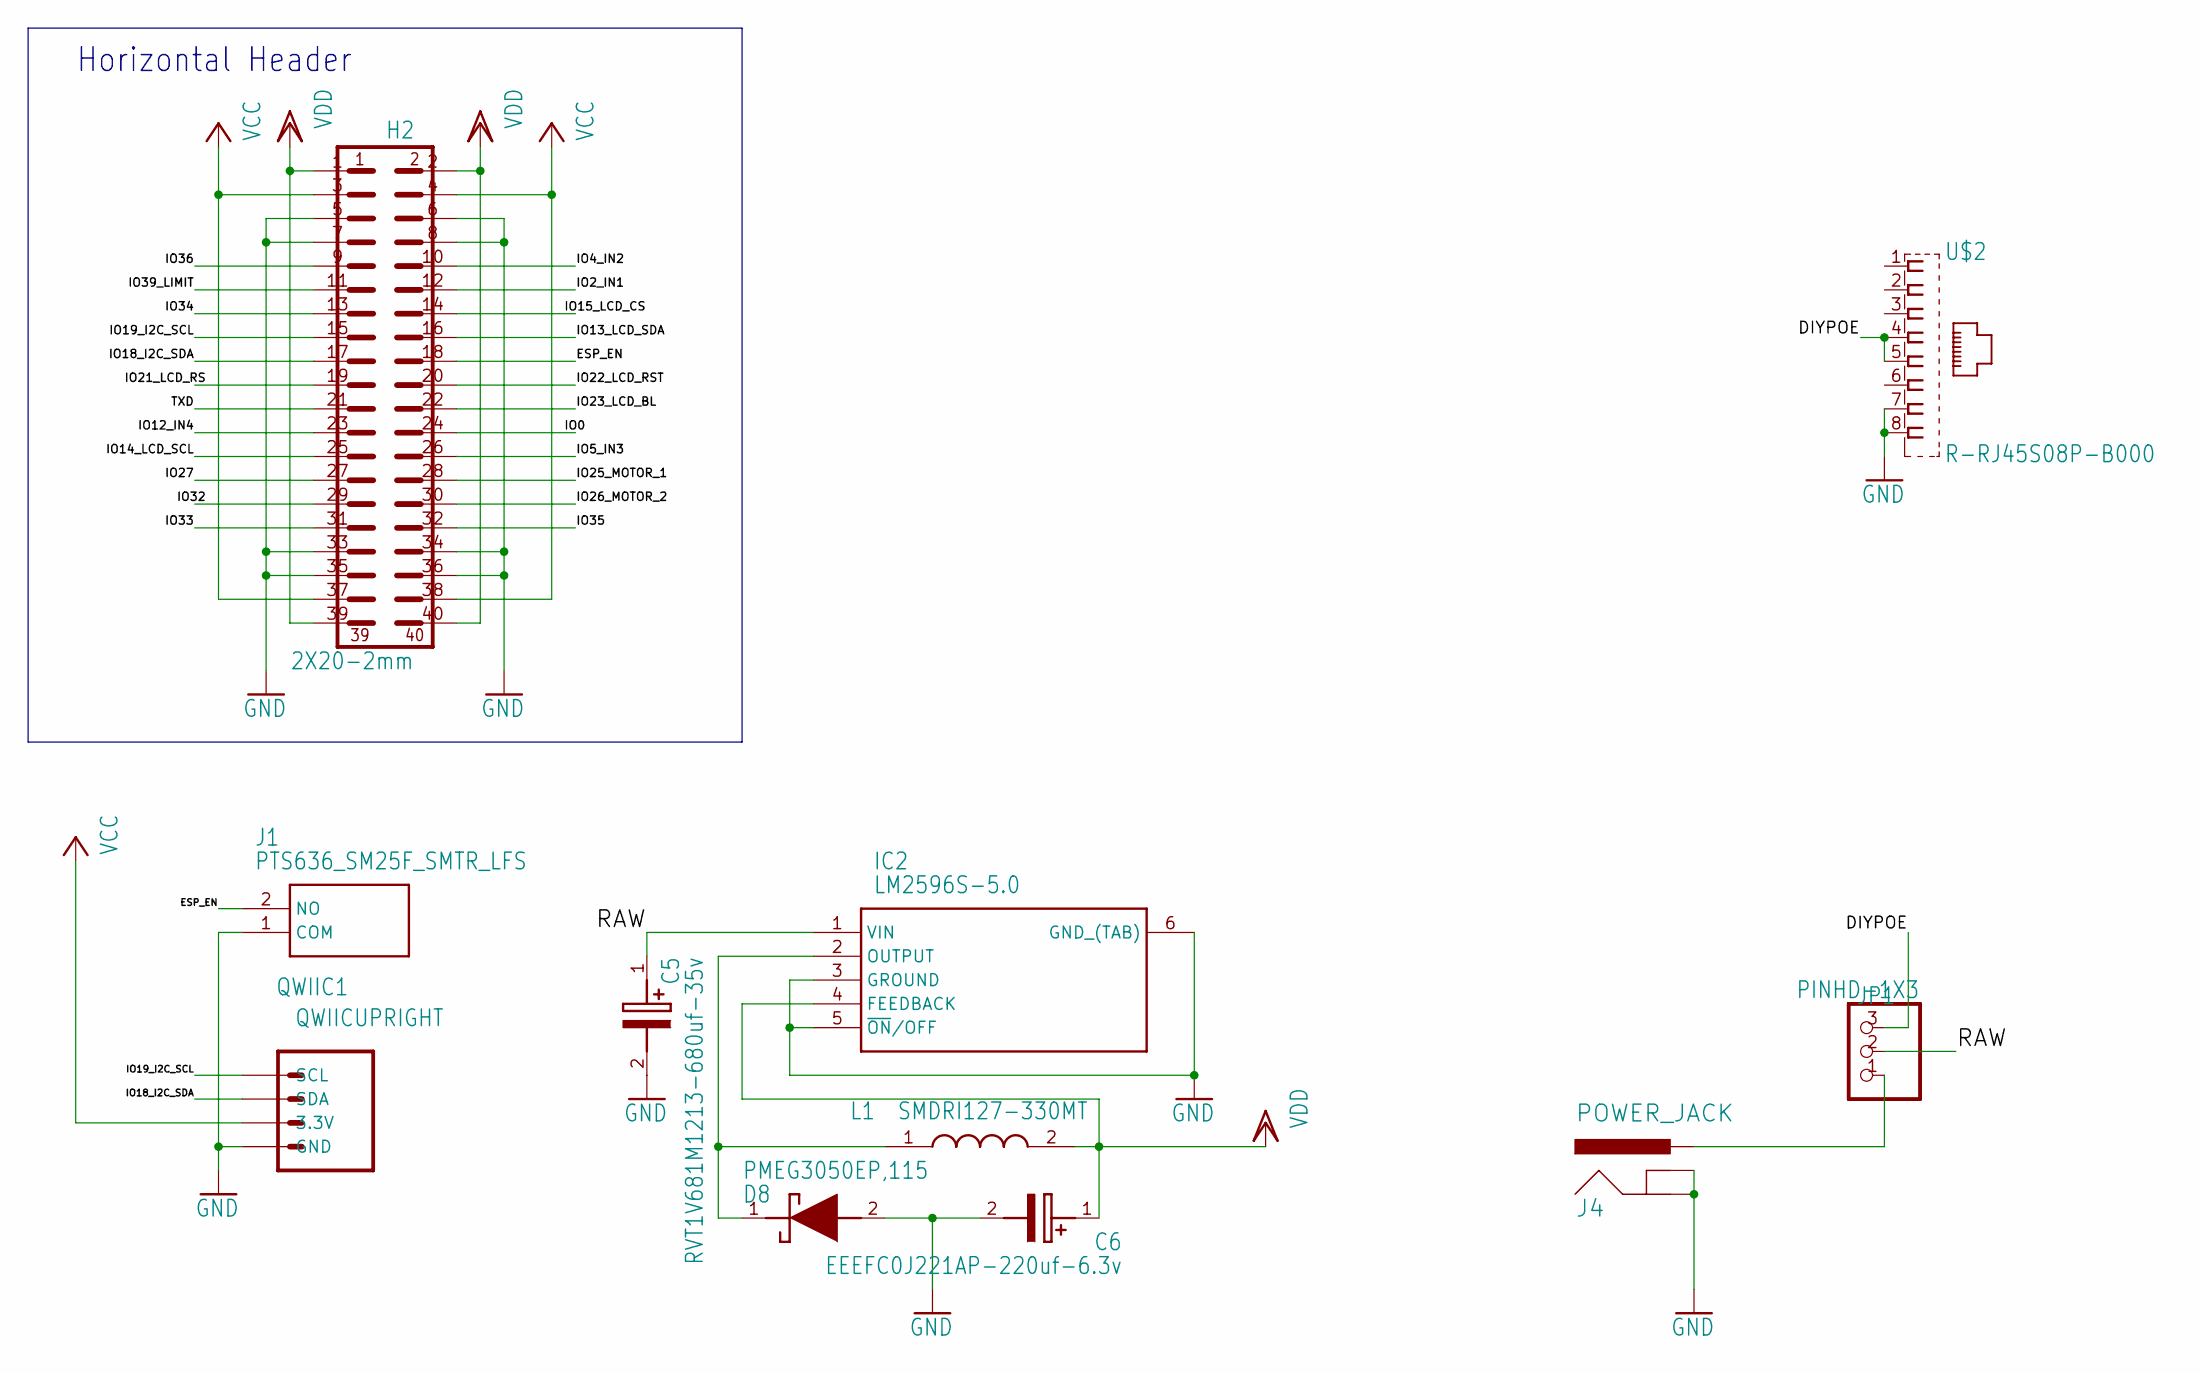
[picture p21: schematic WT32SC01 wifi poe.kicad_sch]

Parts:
C5: RVT1V681M1213-680uf-35v; CAPAE1350X1400N
C6: EEEFC0J221AP-220uf-6.3v; CAPAE830X650N
D8: PMEG3050EP,115; PMEG3050EP115
H2: 2X20-2mm; 2X20-2.00-P-BELOW
IC2: LM2596S-5.0; TO170P1435X465-6N
J1: PTS636_SM25F_SMTR_LFS; PTS636SM25FSMTRLFS
J4: POWER_JACK; POWER_JACK_PTH
JP1: PINHD-1X3; 1X03
L1: SMDRI127-330MT; INDPM120120X800N
QWIIC1: QWIICUPRIGHT; BM04B-SRSS-TB
U$2: R-RJ45S08P-B000

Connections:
DIYPOE: JP1.3, U$2.4, U$2.5
ESP_EN: H2.18, J1.2 (NO)
GND: C5.2 (-), C6.2 (-), D8.2 (A), H2.5, H2.6, H2.7, H2.8, H2.33, H2.34, H2.35, H2.36, IC2.3 (GROUND), IC2.5 (~ON/OFF), IC2.6 (GND_(TAB)), J1.1 (COM), J4.GND, J4.GNDBREAK, QWIIC1.1 (GND), U$2.7, U$2.8
IO0: H2.24
IO2_IN1: H2.12
IO4_IN2: H2.10
IO5_IN3: H2.26
IO12_IN4: H2.23
IO13_LCD_SDA: H2.16
IO14_LCD_SCL: H2.25
IO15_LCD_CS: H2.14
IO18_I2C_SDA: H2.17, QWIIC1.3 (SDA)
IO19_I2C_SCL: H2.15, QWIIC1.4 (SCL)
IO21_LCD_RS: H2.19
IO22_LCD_RST: H2.20
IO23_LCD_BL: H2.22
IO25_MOTOR_1: H2.28
IO26_MOTOR_2: H2.30
IO27: H2.27
IO32: H2.29
IO33: H2.31
IO34: H2.13
IO35: H2.32
IO36: H2.9
IO39_LIMIT: H2.11
unnamed: J4.PWR, JP1.1
unnamed: D8.1 (K), IC2.2 (OUTPUT), L1.1
RAW: C5.1 (+), IC2.1 (VIN), JP1.2
TXD: H2.21
VCC: H2.3, H2.4, H2.37, H2.38, QWIIC1.2 (3.3V)
VDD: C6.1 (+), H2.1, H2.2, H2.39, H2.40, IC2.4 (FEEDBACK), L1.2

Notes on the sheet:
Horizontal Header

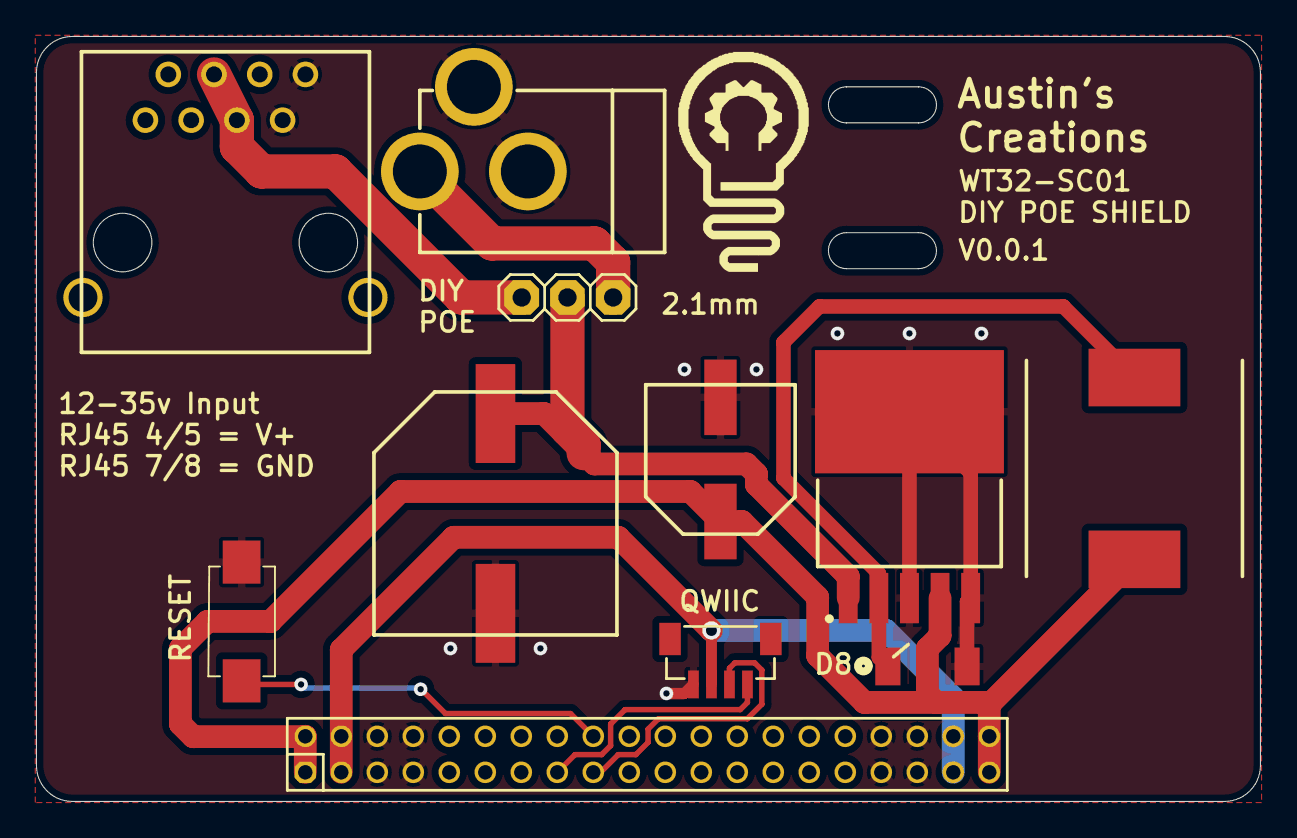
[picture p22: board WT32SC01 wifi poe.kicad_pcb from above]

Board: 2 copper layers, 68.0 x 42.5 mm, 12 parts (0 on the bottom side), 10 nets.

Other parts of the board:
U$1: LOGOMED

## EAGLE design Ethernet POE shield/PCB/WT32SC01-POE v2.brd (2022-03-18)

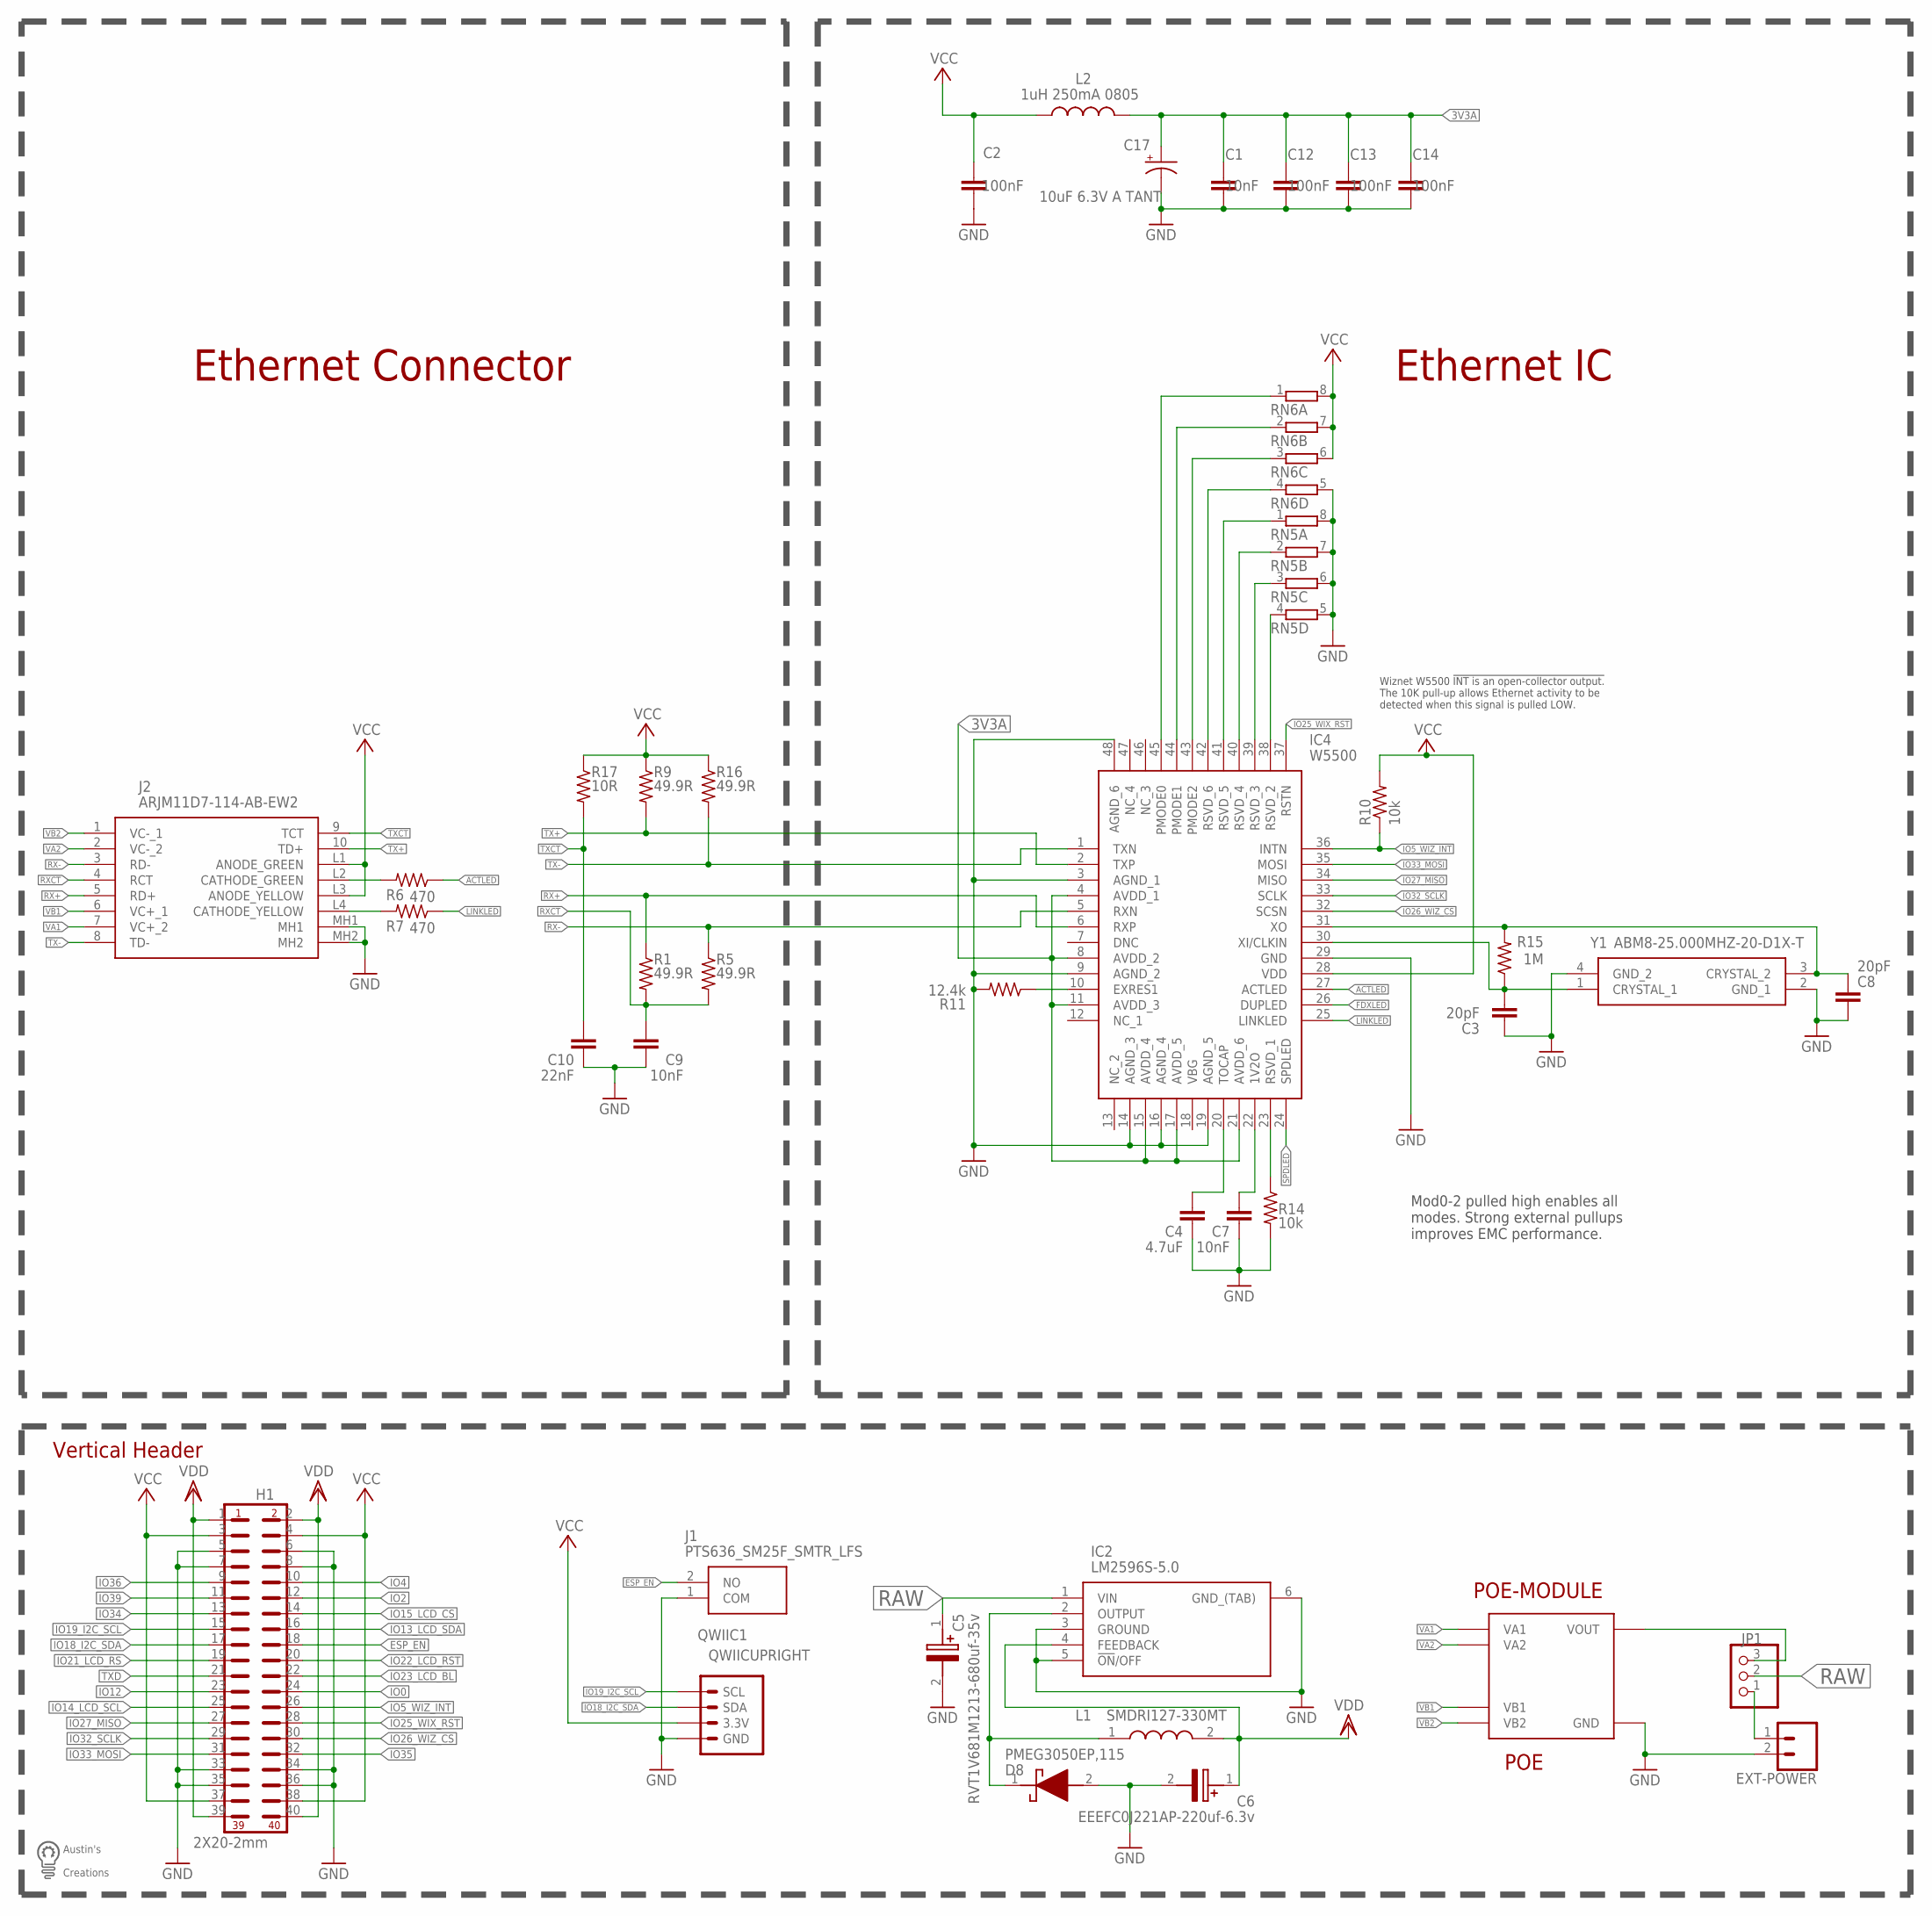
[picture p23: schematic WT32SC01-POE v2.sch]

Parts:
C1, C7, C9: 10nF; C0603
C2, C12, C13, C14: 100nF; C0603
C3, C8: 20pF; C0603
C4: 4.7uF; C0603
C5: RVT1V681M1213-680uf-35v; CAPAE1350X1400N
C6: EEEFC0J221AP-220uf-6.3v; CAPAE830X650N
C10: 22nF; C0603
C17: 10uF 6.3V A TANT; A/3216-18W
D8: PMEG3050EP,115; PMEG3050EP115
EXT-POWER: JL301-50002U02; SCREWTERMINAL-5MM-2
H1: 2X20-2mm; 2X20-2.00-P-BELOW
IC2: LM2596S-5.0; TO170P1435X465-6N
IC4: W5500; QFP50P900X900X160-48N
J1: PTS636_SM25F_SMTR_LFS; PTS636SM25FSMTRLFS
J2: ARJM11D7-114-AB-EW2; ARJM11D7114ABEW2
JP1: PINHD-1X3; 1X03
L1: SMDRI127-330MT; INDPM120120X800N
L2: 1uH 250mA 0805; L2012C
POE-MODULE: POE; DP1435
QWIIC1: QWIICUPRIGHT; BM04B-SRSS-TB
R1, R5, R9, R16: 49.9R; R0603
R6, R7: 470; R0603
R10, R14: 10k; R0603
R11: 12.4k; R0603
R15: 1M; R0603
R17: 10R; R0603
RN5, RN6: 4R-N0603-ARC; 0603-ARC
U$1: LOGOMED
Y1: ABM8-25.000MHZ-20-D1X-T; ABM825000MHZ10B1UT

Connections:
3V3A: C1.1, C12.1, C13.1, C14.1, C17.+, IC4.4 (AVDD_1), IC4.8 (AVDD_2), IC4.11 (AVDD_3), IC4.15 (AVDD_4), IC4.17 (AVDD_5), IC4.21 (AVDD_6), L2.2
ACTLED: IC4.27 (ACTLED), R6.1
ESP_EN: H1.18, J1.2 (NO)
FDXLED: IC4.26 (DUPLED)
GND: C1.2, C2.2, C3.1, C4.1, C5.2 (-), C6.2 (-), C7.1, C8.1, C9.1, C10.1, C12.2, C13.2, C14.2, C17.-, D8.2 (A), EXT-POWER.2, H1.5, H1.6, H1.7, H1.8, H1.33, H1.34, H1.35, H1.36, IC2.3 (GROUND), IC2.5 (!ON!/OFF), IC2.6 (GND_(TAB)), IC4.3 (AGND_1), IC4.9 (AGND_2), IC4.14 (AGND_3), IC4.16 (AGND_4), IC4.19 (AGND_5), IC4.29 (GND), IC4.48 (AGND_6), J1.1 (COM), J2.MH1, J2.MH2, POE-MODULE.GND, QWIIC1.1 (GND), R11.2, R14.2, RN5.5 (2), RN5.6 (2), RN5.7 (2), RN5.8 (2), RN6.5 (2), Y1.2 (GND_1), Y1.4 (GND_2)
IO0: H1.24
IO2: H1.12
IO4: H1.10
IO5_WIZ_INT: H1.26, IC4.36 (INTN), R10.1
IO12: H1.23
IO13_LCD_SDA: H1.16
IO14_LCD_SCL: H1.25
IO15_LCD_CS: H1.14
IO18_I2C_SDA: H1.17, QWIIC1.3 (SDA)
IO19_I2C_SCL: H1.15, QWIIC1.4 (SCL)
IO21_LCD_RS: H1.19
IO22_LCD_RST: H1.20
IO23_LCD_BL: H1.22
IO25_WIX_RST: H1.28, IC4.37 (RSTN)
IO26_WIZ_CS: H1.30, IC4.32 (SCSN)
IO27_MISO: H1.27, IC4.34 (MISO)
IO32_SCLK: H1.29, IC4.33 (SCLK)
IO33_MOSI: H1.31, IC4.35 (MOSI)
IO34: H1.13
IO35: H1.32
IO36: H1.9
IO39: H1.11
LINKLED: IC4.25 (LINKLED), R7.1
unnamed: EXT-POWER.1, JP1.1
unnamed: IC4.10 (EXRES1), R11.1
unnamed: IC4.23 (RSVD_1), R14.1
unnamed: IC4.38 (RSVD_2), RN5.4 (1)
unnamed: IC4.39 (RSVD_3), RN5.3 (1)
unnamed: IC4.40 (RSVD_4), RN5.2 (1)
unnamed: IC4.41 (RSVD_5), RN5.1
unnamed: IC4.42 (RSVD_6), RN6.4 (1)
unnamed: C8.2, IC4.31 (XO), R15.2, Y1.3 (CRYSTAL_2)
unnamed: IC4.43 (PMODE2), RN6.3 (1)
unnamed: IC4.44 (PMODE1), RN6.2 (1)
unnamed: IC4.45 (PMODE0), RN6.1
unnamed: C3.2, IC4.30 (XI/CLKIN), R15.1, Y1.1 (CRYSTAL_1)
unnamed: JP1.3, POE-MODULE.VOUT
unnamed: J2.L2 (CATHODE_GREEN), R6.2
unnamed: D8.1 (K), IC2.2 (OUTPUT), L1.1
unnamed: J2.L4 (CATHODE_YELLOW), R7.2
unnamed: C7.2, IC4.22 (1V2O)
unnamed: C4.2, IC4.20 (TOCAP)
RAW: C5.1 (+), IC2.1 (VIN), JP1.2
RX+: IC4.6 (RXP), J2.5 (RD+), R1.1
RX-: IC4.5 (RXN), J2.3 (RD-), R5.1
RXCT: C9.2, J2.4 (RCT), R1.2, R5.2
SPDLED: IC4.24 (SPDLED)
TX+: IC4.2 (TXP), J2.10 (TD+), R9.2
TX-: IC4.1 (TXN), J2.8 (TD-), R16.2
TXCT: C10.2, J2.9 (TCT), R17.2
TXD: H1.21
VA1: J2.7 (VC+_2), POE-MODULE.VA1
VA2: J2.2 (VC-_2), POE-MODULE.VA2
VB1: J2.6 (VC+_1), POE-MODULE.VB1
VB2: J2.1 (VC-_1), POE-MODULE.VB2
VCC: C2.1, H1.3, H1.4, H1.37, H1.38, IC4.28 (VDD), J2.L1 (ANODE_GREEN), J2.L3 (ANODE_YELLOW), L2.1, QWIIC1.2 (3.3V), R9.1, R10.2, R16.1, R17.1, RN6.6 (2), RN6.7 (2), RN6.8 (2)
VDD: C6.1 (+), H1.1, H1.2, H1.39, H1.40, IC2.4 (FEEDBACK), L1.2

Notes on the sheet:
Vertical Header
Mod0-2 pulled high enables all modes. Strong external pullups improves EMC performance.
Wiznet W5500 !INT is an open-collector output. The 10K pull-up allows Ethernet activity to be detected when this signal is pulled LOW.
Ethernet IC
Ethernet Connector

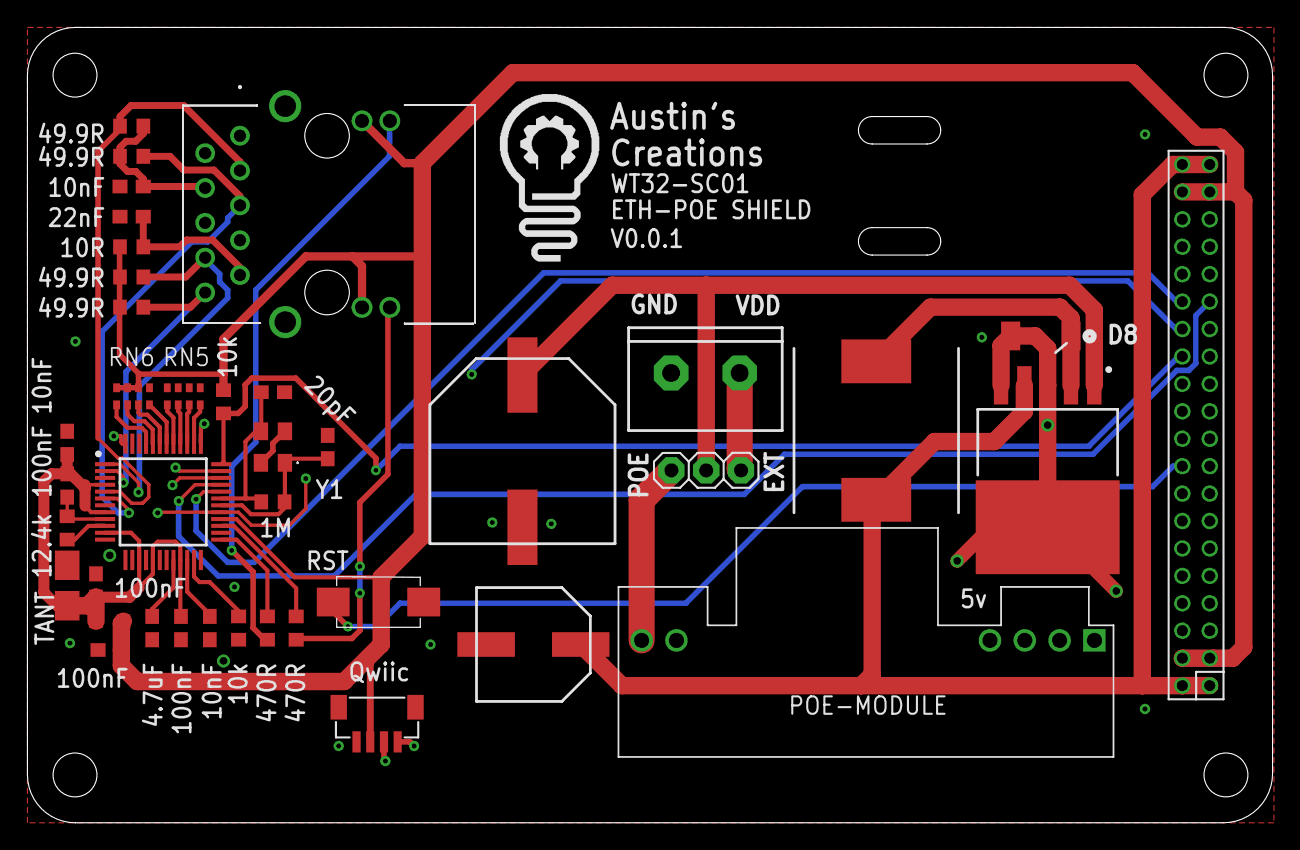
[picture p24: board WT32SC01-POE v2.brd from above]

Board: 4 copper layers, 90.8 x 58.0 mm, 41 parts (0 on the bottom side), 45 nets.

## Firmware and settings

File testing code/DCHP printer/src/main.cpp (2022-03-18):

#include <Arduino.h>
#include <WiFi.h> 
#include <SPI.h>
#include <Ethernet.h>
#include <OXRS_MQTT.h>                // For MQTT
#include <OXRS_API.h>                 // For REST API
// #include <EthernetSPI2.h>

/*--------------------------- Version ------------------------------------*/
#define FW_NAME       "OXRS-AC-WT32_SC01_ETH_TEST-ESP32-FW"
#define FW_SHORT_NAME "ETH TEST"
#define FW_MAKER      "Austin's Creations"
#define FW_VERSION    "0.0.1"


#define       ETH_SCLK                  32
#define       ETH_MISO                  27
#define       ETH_MOSI                  33
#define       ETHERNET_CS_PIN           26
#define       WIZNET_RESET_PIN          25
#define       DHCP_TIMEOUT_MS           15000
#define       DHCP_RESPONSE_TIMEOUT_MS  4000

#define       DISPLAY_CS_PIN            15

// Serial
#define       SERIAL_BAUD_RATE          115200

// client && server
EthernetClient client;
EthernetServer server(80);

// MQTT client
PubSubClient mqttClient(client);
OXRS_MQTT mqtt(mqttClient);

// API connection
OXRS_API api(mqtt);


void initialiseEthernet(byte * mac)
{
  // Get ESP32 base MAC address
  WiFi.macAddress(mac);
  
  // Ethernet MAC address is base MAC + 3
  // See https://docs.espressif.com/projects/esp-idf/en/latest/esp32/api-reference/system/system.html#mac-address
  mac[5] += 3;

  // Display the MAC address on serial
  char mac_display[18];
  sprintf_P(mac_display, PSTR("%02X:%02X:%02X:%02X:%02X:%02X"), mac[0], mac[1], mac[2], mac[3], mac[4], mac[5]);
  Serial.print(F(" mac address: "));
  Serial.println(mac_display);

  // Initialise ethernet library
  Ethernet.init(ETHERNET_CS_PIN);

  // Reset Wiznet W5500
  pinMode(WIZNET_RESET_PIN, OUTPUT);
  digitalWrite(WIZNET_RESET_PIN, HIGH);
  delay(250);
  digitalWrite(WIZNET_RESET_PIN, LOW);
  delay(50);
  digitalWrite(WIZNET_RESET_PIN, HIGH);
  delay(350);

  // Get an IP address via DHCP and display on serial
  Serial.print(F("ip address: "));
  SPI.begin(ETH_SCLK, ETH_MISO, ETH_MOSI, ETHERNET_CS_PIN);
  if (Ethernet.begin(mac, DHCP_TIMEOUT_MS, DHCP_RESPONSE_TIMEOUT_MS))
  {
    Serial.println(Ethernet.localIP());
  }
  else
  {
    Serial.println("Failed to configure Ethernet using DHCP");
    if (Ethernet.hardwareStatus() == EthernetNoHardware) {
      Serial.println("Ethernet shield was not found.  Sorry, can't run without hardware. :(");
    } else if (Ethernet.linkStatus() == LinkOFF) {
      Serial.println("Ethernet cable is not connected.");
    }
  }
}

/**
  MQTT
*/
void mqttCallback(char * topic, uint8_t * payload, unsigned int length) 
{
  // Pass this message down to our MQTT handler
  mqtt.receive(topic, payload, length);
}


void getFirmwareJson(JsonVariant json)
{
  JsonObject firmware = json.createNestedObject("firmware");

  firmware["name"] = FW_NAME;
  firmware["shortName"] = FW_SHORT_NAME;
  firmware["maker"] = FW_MAKER;
  firmware["version"] = FW_VERSION;
}

void getNetworkJson(JsonVariant json)
{
  byte mac[6];
  WiFi.macAddress(mac);
  
  char mac_display[18];
  sprintf_P(mac_display, PSTR("%02X:%02X:%02X:%02X:%02X:%02X"), mac[0], mac[1], mac[2], mac[3], mac[4], mac[5]);

  JsonObject network = json.createNestedObject("network");


  network["ip"] = Ethernet.localIP();

  network["mac"] = mac_display;
}

void getConfigSchemaJson(JsonVariant json)
{
  JsonObject configSchema = json.createNestedObject("configSchema");
  
  // Config schema metadata
  configSchema["$schema"] = "http://json-schema.org/draft-07/schema#";
  configSchema["title"] = FW_NAME;
  configSchema["type"] = "object";



}

void getCommandSchemaJson(JsonVariant json)
{
  JsonObject commandSchema = json.createNestedObject("commandSchema");
  
  // Command schema metadata
  commandSchema["$schema"] = "http://json-schema.org/draft-07/schema#";
  commandSchema["title"] = FW_NAME;
  commandSchema["type"] = "object";


}


/**
  API callbacks
*/
void apiAdopt(JsonVariant json)
{
  // Build device adoption info
  getFirmwareJson(json);
  getNetworkJson(json);
  getConfigSchemaJson(json);
  getCommandSchemaJson(json);
}

/**
  MQTT callbacks
*/
void mqttConnected() 
{
  // Build device adoption info
  // Build device adoption info
  DynamicJsonDocument json(JSON_ADOPT_MAX_SIZE);
  mqtt.publishAdopt(api.getAdopt(json.as<JsonVariant>()));

  // Log the fact we are now connected
  Serial.println("[TLC] mqtt connected");
}

void mqttDisconnected(int state) 
{
  // Log the disconnect reason
  // See https://github.com/knolleary/pubsubclient/blob/2d228f2f862a95846c65a8518c79f48dfc8f188c/src/PubSubClient.h#L44
  switch (state)
  {
    case MQTT_CONNECTION_TIMEOUT:
      Serial.println(F("[TLC] mqtt connection timeout"));
      break;
    case MQTT_CONNECTION_LOST:
      Serial.println(F("[TLC] mqtt connection lost"));
      break;
    case MQTT_CONNECT_FAILED:
      Serial.println(F("[TLC] mqtt connect failed"));
      break;
    case MQTT_DISCONNECTED:
      Serial.println(F("[TLC] mqtt disconnected"));
      break;
    case MQTT_CONNECT_BAD_PROTOCOL:
      Serial.println(F("[TLC] mqtt bad protocol"));
      break;
    case MQTT_CONNECT_BAD_CLIENT_ID:
      Serial.println(F("[TLC] mqtt bad client id"));
      break;
    case MQTT_CONNECT_UNAVAILABLE:
      Serial.println(F("[TLC] mqtt unavailable"));
      break;
    case MQTT_CONNECT_BAD_CREDENTIALS:
      Serial.println(F("[TLC] mqtt bad credentials"));
      break;      
    case MQTT_CONNECT_UNAUTHORIZED:
      Serial.println(F("[TLC] mqtt unauthorised"));
      break;      
  }
}

void jsonConfig(JsonVariant json) // config payload
{

}

void jsonCommand(JsonVariant json) // do something payloads
{  


  if (json.containsKey("restart") && json["restart"].as<bool>())
  {
    ESP.restart();
  }
}





/*
 MQTT
 */
void initialiseMqtt(byte * mac)
{
  // Set the default client id to the last 3 bytes of the MAC address
  char clientId[32];
  sprintf_P(clientId, PSTR("%02x%02x%02x"), mac[3], mac[4], mac[5]);  
  mqtt.setClientId(clientId);
  
  // Register our callbacks
  mqtt.onConnected(mqttConnected);
  mqtt.onDisconnected(mqttDisconnected);
  mqtt.onConfig(jsonConfig);
  mqtt.onCommand(jsonCommand);  

  // Start listening for MQTT messages
  mqttClient.setCallback(mqttCallback);  
}


/*
 REST API
 */
void initialiseRestApi(void)
{
  // NOTE: this must be called *after* initialising MQTT since that sets
  //       the default client id, which has lower precendence than MQTT
  //       settings stored in file and loaded by the API

  // Set up the REST API
  api.begin();

  // Register our callbacks
  api.onAdopt(apiAdopt);

  server.begin();
}


void setup() {

  Serial.begin(SERIAL_BAUD_RATE);
  delay(1000);
  Serial.println();
  Serial.println(F("\n==============================="));
  Serial.println(FW_NAME);
  Serial.print  (F("            v"));
  Serial.println(FW_VERSION);
  Serial.println(F("==============================="));

  pinMode(DISPLAY_CS_PIN, OUTPUT);
  digitalWrite(DISPLAY_CS_PIN, HIGH);

  // SPI.begin (SPI_SCK, SPI_MISO, SPI_MOSI);

  // Set up ethernet and obtain an IP address
  byte mac[6];
  initialiseEthernet(mac);

  initialiseMqtt(mac);   // Set up MQTT (don't attempt to connect yet)

  initialiseRestApi();   // Set up the REST API

}

void loop() {
  Ethernet.maintain();

  EthernetClient client = server.available();
  api.checkEthernet(&client);

}

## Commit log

2022-03-18 adding custom 3d printable wall plate mount
    [AUS mount.stl, NA mount.stl, screen case extra height.stl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]
2022-06-23 update for new boards
2022-06-23 preparing repo overhaul
    [WT32SC01-POE v2.brd, WT32SC01-POE v2.sch, WT32SC01-POE v2_top_bom.csv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]
2022-06-23 add new wifi and ethernet designs
    [ARJM11D7114ABEW2.step, AUS mount.stl, NA mount.stl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]
2022-06-28 new versions
    [WT32-SC01 wifi case AUS 3mm standoff.stl, WT32-SC01 wifi case AUS 6mm standoff.stl, WT32-SC01 wifi case NA 3mm standoff.stl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]
2022-06-28 obsolete design
    [WT32-SC01 slim case for wifi v1 AUS.stl]
2022-06-29 add case option for no usb
2022-06-29 add no usb case options
    [WT32-SC01 wifi case AUS 3mm standoff no usb.stl, WT32-SC01 wifi case AUS 6mm standoff no usb.stl, WT32-SC01 wifi case NA 3mm standoff no usb.stl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]
2023-06-28 adding latest POE shield
    [BOM-WT32 Ethernet POE 006 v2.csv, BOM-WT32 Ethernet POE 006 v2.xls, BOM-WT32 Ethernet POE 006.csv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]
2023-08-02 adding 86s panel support
    [BOM-WT32-86s adapter.csv, WT32-86s adapter.kicad_pcb, WT32-86s adapter.kicad_sch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]
2023-08-02 add schematic image
2023-09-18 nudged the large inductor
    [WT32 Ethernet POE 006.kicad_pcb]
2023-09-18 update inductor footprint
2024-05-23 rev 6 obsolete
    5v regulator not stable long term - new design coming
    [BOM-WT32 Ethernet POE 006 v2.xls, WT32 Ethernet POE 006.kicad_pcb, WT32 ethernet POE 006.kicad_sch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]
2024-05-23 add plus screen POE NA screen mount
    [plus NA screen backer.stl, plus screen cover.stl, plus screen holder.stl]
2024-09-11 add the holder for the wt32sc01-plus screen
    [plus NA screen backer.stl, plus screen cover.stl, plus screen holder.stl]
2024-09-11 Revert "add the holder for the wt32sc01-plus screen"
    This reverts commit c838f73afda2a925ba6b19c164f577740880c950.
    [plus NA screen backer.stl, plus screen cover.stl, plus screen holder.stl]
